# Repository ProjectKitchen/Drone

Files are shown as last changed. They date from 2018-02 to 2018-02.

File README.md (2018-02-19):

# Drone

## Disclaimer
This is drone was created in the winter term 2014 by students in the mechatronics/robotics degree course. It was added to the ProjectKitchen for further development

## Description
The projects aim was to create an inexpensive drone that could be used for swarm experiments. It comprises of the following components:
- A flight controller (MultiWii 328p available at Hobbyking)
- A MOSFET-Driver with DC-motors (can be substituted with brushless motors & ESCs)
- A Bluetooth HC06 module for communication (should be substituted with a WiFi-module)
- A Arduino Micro for communication & as a possible hook for swarm algorithms

## ToDo
- Get a battery for that drone
- Modify the base to be printed on our 3D-printer
- Get stronger motors for acrobatic flights

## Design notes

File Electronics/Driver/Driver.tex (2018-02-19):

\documentclass{article}

\usepackage[utf8]{inputenc}
\usepackage[T1]{fontenc}
\usepackage[ngerman]{babel}
\usepackage{helvet}
\renewcommand{\familydefault}{cmss}
\usepackage[natural, table, fixpdftex, hyperref]{xcolor}
\usepackage{tikz}
\usepackage[european, emptydiodes, arrowmos, smartlabels, siunitx]{circuitikz}
\usetikzlibrary{shapes,arrows,positioning,matrix}

%%%<
\usepackage{verbatim}
\usepackage[active,tightpage]{preview}
\PreviewEnvironment{tikzpicture}
\setlength\PreviewBorder{2pt}%
%%%>

\begin{comment}
:Title: Einzeltreiber-Schaltung
:Copyright: Otrebski
\end{comment}

% Motor taken from: http://tex.stackexchange.com/questions/132076/how-to-draw-a-dc-motor-in-circuitikz
% prepare to create bipoles
\makeatletter
\def\TikzBipolePath#1#2{\pgf@circ@bipole@path{#1}{#2}}
\def\CircDirection{\pgf@circ@direction}
\pgf@circ@Rlen = \pgfkeysvalueof{/tikz/circuitikz/bipoles/length}
\makeatother 
\newlength{\ResUp} \newlength{\ResDown}
\newlength{\ResLeft} \newlength{\ResRight}
% set default motor size
\ctikzset{bipoles/motor/height/.initial=.8}
\ctikzset{bipoles/motor/width/.initial=.8}
% create motor shape
\pgfcircdeclarebipole{}
 {\ctikzvalof{bipoles/motor/height}}
 {motor}
 {\ctikzvalof{bipoles/motor/height}}
 {\ctikzvalof{bipoles/motor/width}}
 {
    \pgfsetlinewidth{\ctikzvalof{bipoles/thickness}\pgfstartlinewidth}
    \pgfextractx{\ResRight}{\northeast}
    \pgfextracty{\ResUp}{\northeast}
    \pgfextractx{\ResLeft}{\southwest}
    \pgfextracty{\ResDown}{\southwest}
  \pgfpathmoveto{\pgfpoint{0.775\ResLeft}{0.2\ResDown}}
\pgfpathlineto{\pgfpoint{\ResLeft}{0.2\ResDown}}
  \pgfpathlineto{\pgfpoint{\ResLeft}{0.2\ResUp}}
  \pgfpathlineto{\pgfpoint{0.775\ResLeft}{0.2\ResUp}}
\pgfpathellipse{\pgfpointorigin}{\pgfpoint{0.8\ResRight}{0cm}}
    {\pgfpoint{0cm}{0.8\ResUp}}
  \pgfpathmoveto{\pgfpoint{0.775\ResRight}{0.2\ResDown}}
    \pgfpathlineto{\pgfpoint{\ResRight}{0.2\ResDown}}
  \pgfpathlineto{\pgfpoint{\ResRight}{0.2\ResUp}}
  \pgfpathlineto{\pgfpoint{0.775\ResRight}{0.2\ResUp}}
  \pgfusepath{draw} %draw motor
    \pgftext[rotate=-\CircDirection]{\textsf{M}}
 }
% create motorto-path style
\def\motorpath#1{\TikzBipolePath{motor}{#1}}
\tikzset{motor/.style = {\circuitikzbasekey, /tikz/to path=\motorpath, l=#1}}
% end of setup

\begin{document}
\pagestyle{empty}

% Define block styles
\tikzstyle{block} = [rectangle, draw, fill=blue!20,
    text width=10em, text centered, minimum height=2em]
\tikzstyle{line} = [draw, latex'-latex', thick]
    
\begin{circuitikz}[auto, node distance =15em]
	\node[anchor=east](start)at(0,0){Flight-Controller};
	\node[nigfete,anchor=G](MOSFET)at(3,0){IPS105N03LG};
	\draw(MOSFET.D) -- ++(0,0.5)node[circ](tmp1){} to[motor] ++(0,2.5)node[circ](tmp2){} -- ++(1,0)node[at end, anchor=west]{Batterie +};
	\draw(start.east) to[R,l=150<\ohm>](MOSFET.G);
	\draw(MOSFET.G) ++(-0.25,0)node[circ](tmp3){};
	\draw(tmp1) -- ++(-1,0) to[diode] ++(0,2.5) --(tmp2);
	\draw(MOSFET.S) -- ++(0,-1.5)node[circ](tmp4){} --++(1,0)node[at end, anchor=west]{Batterie --};
	\draw(tmp3) to[R, l_=10<\kilo\ohm>](tmp3|-tmp4)--(tmp4);
	\node at(-0.5,-2){\scriptsize Driver circiut for DC-motors};
\end{circuitikz}

\end{document}

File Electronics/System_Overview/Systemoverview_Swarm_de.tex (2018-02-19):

\documentclass{article}

\usepackage[utf8]{inputenc}
\usepackage[T1]{fontenc}
\usepackage[ngerman]{babel}
\usepackage{helvet}
\renewcommand{\familydefault}{cmss}
\usepackage[natural, table, fixpdftex, hyperref]{xcolor}
\usepackage{tikz}
\usetikzlibrary{shapes,arrows,positioning,matrix}

%%%<
\usepackage{verbatim}
\usepackage[active,tightpage]{preview}
\PreviewEnvironment{tikzpicture}
\setlength\PreviewBorder{2pt}%
%%%>

\begin{comment}
:Title: Systemarchitektur bei Schwarm
:Copyright: Otrebski
\end{comment}

\begin{document}
\pagestyle{empty}

% Define block styles
\tikzstyle{block} = [rectangle, draw, fill=blue!20,
    text width=11em, text centered, minimum height=2em]
\tikzstyle{line} = [draw, latex'-latex', thick]

\begin{tikzpicture}[auto, node distance =15em, font=\large]
	\node[block](controller){Mikrocontroller};
	\node[block, above right of =controller, node distance = 12em](hive){Schwarmintelligenz};
	\node[block, above of =hive, node distance=6em](com){Kommunikation};
	\node[block, below left of =controller, node distance =10em](gyro){Gyroskop};
	\node[block, below right of =controller, node distance =10em](mag){Magnetometer};
	\node[block, left of =gyro](acc){Beschleunigungsmesser};
	\node[block, right of =mag](baro){Barometer};
	\coordinate[shift={(-2em,2em)}] (FC1) at (acc.west|-controller.north);
	\coordinate[shift={(2em,-2em)}] (FC2) at (baro.south-|baro.east);
	\draw[dashed] (FC1) rectangle (FC2);
	\node[anchor=north west] at (FC1) {Flight-Controller};
	%\node[block, below left of =gyro, node distance = 12em](action){Antrieb};
	\node[block, below of =controller, node distance =15em](action){Antrieb};
	%\node[block, below right of =gyro, node distance = 12em](peripherie){Peripherie};
	\node[block, left of =hive, node distance = 20em](peripherie){Peripherie};
	\path[line] (hive) -- (FC1-|com)node[midway]{Servo-Signal Bus \& Serielle Schnittstelle};
	\path[line] (hive) -- (com)node[midway, right]{Serielle Schnittstelle};
	\path[line] (action) -- (FC2-|action)node[midway, right]{PWM-Signal Bus};
	\path[line] (peripherie) -- (hive)node[midway,above]{I\textsuperscript{2}C-Protokoll};
	\path[line] (controller.west) ++(0,0.5em)-| (acc);
	\path[line] (controller.west) ++(0,-0.5em)-| (gyro);
	\path[line] (controller.east) ++(0,0.5em)-| (baro);
	\path[line] (controller.east) ++(0,-0.5em)-| (mag);
	%\node[block](switch){Switch};
	%\node[block, above of =switch](hmi){HMI};
	%\node[block, below left of = switch](cam){Kamera};
	%\node[block, below right of = switch](robot){Roboter};
	%\node[block, below of = robot](enc-splitter){Encoder-Splitter};
	%\node[block, right of = enc-splitter, node distance = 10 em](encoder){Encoder};
	%\node[block, right of = encoder, node distance = 12.5 em](conveyor){F"orderband};
	%Linien
	%\path[line](hmi)--(switch)node[midway, text width = 4em, text badly centered]{Ethernet- Kabel};
	%\path[line](switch)-|(cam)node[midway, left, text width = 4em, text badly centered]{Ethernet- Kabel};
	%\path[line](switch)-|(robot)node[midway, right, text width = 4em, text badly centered]{Ethernet- Kabel};
	%\path[line](cam)|-(enc-splitter)node[near start, left, text width = 4em, text badly centered]{Daten- Kabel};
	%\path[line](robot)--(enc-splitter) node[midway, right, text width = 4em, text badly centered]{Daten- Kabel};
	%\path[line](enc-splitter)--(encoder) node[midway, above]{Daten-} node[midway, below]{Kabel};
	%\path[line](encoder)--(conveyor) node [midway, above]{mechanische}node [midway, below]{Kupplung};
\end{tikzpicture}

\end{document}

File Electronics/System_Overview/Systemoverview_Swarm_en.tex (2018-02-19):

\documentclass{article}

\usepackage[utf8]{inputenc}
\usepackage[T1]{fontenc}
\usepackage[ngerman]{babel}
\usepackage{helvet}
\renewcommand{\familydefault}{cmss}
\usepackage[natural, table, fixpdftex, hyperref]{xcolor}
\usepackage{tikz}
\usetikzlibrary{shapes,arrows,positioning,matrix}

%%%<
\usepackage{verbatim}
\usepackage[active,tightpage]{preview}
\PreviewEnvironment{tikzpicture}
\setlength\PreviewBorder{2pt}%
%%%>

\begin{comment}
:Title: Systemarchitektur bei Schwarm
:Copyright: Otrebski
\end{comment}

\begin{document}
\pagestyle{empty}

% Define block styles
\tikzstyle{block} = [rectangle, draw, fill=blue!20,
    text width=11em, text centered, minimum height=2em]
\tikzstyle{line} = [draw, latex'-latex', thick]

\begin{tikzpicture}[auto, node distance =15em, font=\Large]
	\node[block, fill=blue!30](controller){Micro-Controller};
	\node[block, above right of =controller, node distance = 12em, fill=green!30](hive){Swarm Intelligence};
	\node[block, above of =hive, node distance=6em, fill=red!30](com){Communication};
	\node[block, below left of =controller, node distance =10em, fill=blue!30](gyro){Gyroscope};
	\node[block, below right of =controller, node distance =10em, fill=blue!30](mag){Magnetometer};
	\node[block, left of =gyro, fill=blue!30](acc){Accelerometer};
	\node[block, right of =mag, fill=blue!30](baro){Barometer};
	\coordinate[shift={(-2em,2em)}] (FC1) at (acc.west|-controller.north);
	\coordinate[shift={(2em,-2em)}] (FC2) at (baro.south-|baro.east);
	\draw[dashed] (FC1) rectangle (FC2);
	\node[anchor=north west] at (FC1) {Flight-Controller};
	\node[block, below of =controller, node distance =15em, fill=yellow!30](action){Propulsion};
	\node[block, left of =hive, node distance = 25em, fill=white!30](peripherie){Periphery};
	\path[line] (hive) -- (FC1-|com)node[midway]{Servo-Signal Bus \& Serial Interface};
	\path[line] (hive) -- (com)node[midway, right]{Serial Interface};
	\path[line] (action) -- (FC2-|action)node[midway, right]{PWM-Signal Bus};
	\path[line] (peripherie) -- (hive)node[midway,above]{I\textsuperscript{2}C-Interface};
	\path[line] (controller.west) ++(0,0.5em)-| (acc);
	\path[line] (controller.west) ++(0,-0.5em)-| (gyro);
	\path[line] (controller.east) ++(0,0.5em)-| (baro);
	\path[line] (controller.east) ++(0,-0.5em)-| (mag);
\end{tikzpicture}

\begin{tikzpicture}[auto, node distance =15em, font=\Large]
	\node[block, fill=blue!30](controller){Micro-Controller};
	\node[block, above right of =controller, node distance = 12em, fill=gray!40](hive){Swarm Intelligence};
	\node[block, above of =hive, node distance=6em, fill=gray!40](com){Communication};
	\node[block, below left of =controller, node distance =10em, fill=blue!30](gyro){Gyroscope};
	\node[block, below right of =controller, node distance =10em, fill=blue!30](mag){Magnetometer};
	\node[block, left of =gyro, fill=blue!30](acc){Accelerometer};
	\node[block, right of =mag, fill=blue!30](baro){Barometer};
	\coordinate[shift={(-2em,2em)}] (FC1) at (acc.west|-controller.north);
	\coordinate[shift={(2em,-2em)}] (FC2) at (baro.south-|baro.east);
	\draw[dashed] (FC1) rectangle (FC2);
	\node[anchor=north west] at (FC1) {Flight-Controller};
	\node[block, below of =controller, node distance =15em, fill=gray!40](action){Propulsion};
	\node[block, left of =hive, node distance = 25em, fill=gray!40](peripherie){Periphery};
	\path[line] (hive) -- (FC1-|com)node[midway]{Servo-Signal Bus \& Serial Interface};
	\path[line] (hive) -- (com)node[midway, right]{Serial Interface};
	\path[line] (action) -- (FC2-|action)node[midway, right]{PWM-Signal Bus};
	\path[line] (peripherie) -- (hive)node[midway,above]{I\textsuperscript{2}C-Interface};
	\path[line] (controller.west) ++(0,0.5em)-| (acc);
	\path[line] (controller.west) ++(0,-0.5em)-| (gyro);
	\path[line] (controller.east) ++(0,0.5em)-| (baro);
	\path[line] (controller.east) ++(0,-0.5em)-| (mag);
\end{tikzpicture}

\begin{tikzpicture}[auto, node distance =15em, font=\Large]
	\node[block, fill=gray!40](controller){Micro-Controller};
	\node[block, above right of =controller, node distance = 12em, fill=green!30](hive){Swarm Intelligence};
	\node[block, above of =hive, node distance=6em, fill=gray!40](com){Communication};
	\node[block, below left of =controller, node distance =10em, fill=gray!40](gyro){Gyroscope};
	\node[block, below right of =controller, node distance =10em, fill=gray!40](mag){Magnetometer};
	\node[block, left of =gyro, fill=gray!40](acc){Accelerometer};
	\node[block, right of =mag, fill=gray!40](baro){Barometer};
	\coordinate[shift={(-2em,2em)}] (FC1) at (acc.west|-controller.north);
	\coordinate[shift={(2em,-2em)}] (FC2) at (baro.south-|baro.east);
	\draw[dashed] (FC1) rectangle (FC2);
	\node[anchor=north west] at (FC1) {Flight-Controller};
	\node[block, below of =controller, node distance =15em, fill=gray!40](action){Propulsion};
	\node[block, left of =hive, node distance = 25em, fill=gray!40](peripherie){Periphery};
	\path[line] (hive) -- (FC1-|com)node[midway]{Servo-Signal Bus \& Serial Interface};
	\path[line] (hive) -- (com)node[midway, right]{Serial Interface};
	\path[line] (action) -- (FC2-|action)node[midway, right]{PWM-Signal Bus};
	\path[line] (peripherie) -- (hive)node[midway,above]{I\textsuperscript{2}C-Interface};
	\path[line] (controller.west) ++(0,0.5em)-| (acc);
	\path[line] (controller.west) ++(0,-0.5em)-| (gyro);
	\path[line] (controller.east) ++(0,0.5em)-| (baro);
	\path[line] (controller.east) ++(0,-0.5em)-| (mag);
\end{tikzpicture}

\begin{tikzpicture}[auto, node distance =15em, font=\Large]
	\node[block, fill=gray!40](controller){Micro-Controller};
	\node[block, above right of =controller, node distance = 12em, fill=gray!40](hive){Swarm Intelligence};
	\node[block, above of =hive, node distance=6em, fill=red!30](com){Communication};
	\node[block, below left of =controller, node distance =10em, fill=gray!40](gyro){Gyroscope};
	\node[block, below right of =controller, node distance =10em, fill=gray!40](mag){Magnetometer};
	\node[block, left of =gyro, fill=gray!40](acc){Accelerometer};
	\node[block, right of =mag, fill=gray!40](baro){Barometer};
	\coordinate[shift={(-2em,2em)}] (FC1) at (acc.west|-controller.north);
	\coordinate[shift={(2em,-2em)}] (FC2) at (baro.south-|baro.east);
	\draw[dashed] (FC1) rectangle (FC2);
	\node[anchor=north west] at (FC1) {Flight-Controller};
	\node[block, below of =controller, node distance =15em, fill=gray!40](action){Propulsion};
	\node[block, left of =hive, node distance = 25em, fill=gray!40](peripherie){Periphery};
	\path[line] (hive) -- (FC1-|com)node[midway]{Servo-Signal Bus \& Serial Interface};
	\path[line] (hive) -- (com)node[midway, right]{Serial Interface};
	\path[line] (action) -- (FC2-|action)node[midway, right]{PWM-Signal Bus};
	\path[line] (peripherie) -- (hive)node[midway,above]{I\textsuperscript{2}C-Interface};
	\path[line] (controller.west) ++(0,0.5em)-| (acc);
	\path[line] (controller.west) ++(0,-0.5em)-| (gyro);
	\path[line] (controller.east) ++(0,0.5em)-| (baro);
	\path[line] (controller.east) ++(0,-0.5em)-| (mag);
\end{tikzpicture}

\begin{tikzpicture}[auto, node distance =15em, font=\Large]
	\node[block, fill=gray!40](controller){Micro-Controller};
	\node[block, above right of =controller, node distance = 12em, fill=gray!40](hive){Swarm Intelligence};
	\node[block, above of =hive, node distance=6em, fill=gray!40](com){Communication};
	\node[block, below left of =controller, node distance =10em, fill=gray!40](gyro){Gyroscope};
	\node[block, below right of =controller, node distance =10em, fill=gray!40](mag){Magnetometer};
	\node[block, left of =gyro, fill=gray!40](acc){Accelerometer};
	\node[block, right of =mag, fill=gray!40](baro){Barometer};
	\coordinate[shift={(-2em,2em)}] (FC1) at (acc.west|-controller.north);
	\coordinate[shift={(2em,-2em)}] (FC2) at (baro.south-|baro.east);
	\draw[dashed] (FC1) rectangle (FC2);
	\node[anchor=north west] at (FC1) {Flight-Controller};
	\node[block, below of =controller, node distance =15em, fill=yellow!30](action){Propulsion};
	\node[block, left of =hive, node distance = 25em, fill=gray!40](peripherie){Periphery};
	\path[line] (hive) -- (FC1-|com)node[midway]{Servo-Signal Bus \& Serial Interface};
	\path[line] (hive) -- (com)node[midway, right]{Serial Interface};
	\path[line] (action) -- (FC2-|action)node[midway, right]{PWM-Signal Bus};
	\path[line] (peripherie) -- (hive)node[midway,above]{I\textsuperscript{2}C-Interface};
	\path[line] (controller.west) ++(0,0.5em)-| (acc);
	\path[line] (controller.west) ++(0,-0.5em)-| (gyro);
	\path[line] (controller.east) ++(0,0.5em)-| (baro);
	\path[line] (controller.east) ++(0,-0.5em)-| (mag);
\end{tikzpicture}

\begin{tikzpicture}[auto, node distance =15em, font=\Large]
	\node[block, fill=gray!40](controller){Micro-Controller};
	\node[block, above right of =controller, node distance = 12em, fill=gray!40](hive){Swarm Intelligence};
	\node[block, above of =hive, node distance=6em, fill=gray!40](com){Communication};
	\node[block, below left of =controller, node distance =10em, fill=gray!40](gyro){Gyroscope};
	\node[block, below right of =controller, node distance =10em, fill=gray!40](mag){Magnetometer};
	\node[block, left of =gyro, fill=gray!40](acc){Accelerometer};
	\node[block, right of =mag, fill=gray!40](baro){Barometer};
	\coordinate[shift={(-2em,2em)}] (FC1) at (acc.west|-controller.north);
	\coordinate[shift={(2em,-2em)}] (FC2) at (baro.south-|baro.east);
	\draw[dashed] (FC1) rectangle (FC2);
	\node[anchor=north west] at (FC1) {Flight-Controller};
	\node[block, below of =controller, node distance =15em, fill=gray!40](action){Propulsion};
	\node[block, left of =hive, node distance = 25em, fill=white!30](peripherie){Periphery};
	\path[line] (hive) -- (FC1-|com)node[midway]{Servo-Signal Bus \& Serial Interface};
	\path[line] (hive) -- (com)node[midway, right]{Serial Interface};
	\path[line] (action) -- (FC2-|action)node[midway, right]{PWM-Signal Bus};
	\path[line] (peripherie) -- (hive)node[midway,above]{I\textsuperscript{2}C-Interface};
	\path[line] (controller.west) ++(0,0.5em)-| (acc);
	\path[line] (controller.west) ++(0,-0.5em)-| (gyro);
	\path[line] (controller.east) ++(0,0.5em)-| (baro);
	\path[line] (controller.east) ++(0,-0.5em)-| (mag);
\end{tikzpicture}

\end{document}

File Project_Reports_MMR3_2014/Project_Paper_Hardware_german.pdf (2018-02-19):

Master-Studiengang Mechatronik/Robotik FH Technikum Wien, Höchstädtplatz 5, A-1200 Wien

FH Technikum Wien Drohne
Mechanische und elektrische Auslegung

Student: Otrebski, Richard, BSc, PK: 1310331006 BegutachterIn: Dipl.-Ing. Dr. Trenker, Markus

Kurzfassung: Kommerziell verfügbare Drohnen werden in zivilen Bereichen, wie der Film- und Spielzeugindustrie, und in militärischen Bereichen zum Kartographieren von Gelände oder Suchen von Personen eingesetzt. Diese Modelle sind jedoch für Studenten und Forscher im Bereich von Schwarmaufgaben nicht interessant, da sie zu viel kosten. Günstige Modelle weisen jedoch nicht den benötigten Funktionsumfang auf um Schwarmexperimente durchzuführen. Die Drohne selbst ist mit ihren verschiedensten Komponenten ein interessantes mechatronisches System. Sie zeigt Studenten was ein funktionierendes System umfasst, und wie man die einzelnen Teile auslegt. Damit eignet sie sich ideal für Studenten um ihr Wissen zu erweitern und ihre Fertigkeiten praktisch anzuwenden. In dieser Arbeit wurde die mechanische und elektrische Auslegung einer preiswerten Drohne für Studenten und Schwarmexperimente dokumentiert. Neben einer groben Abschätzung der Antriebsleistung der Motoren und Propeller, wurde auch eine Treiberschaltung konzipiert, die für bürstenbehaftete Motoren verwendet werden kann. Die verwendete Soft- und Hardware ist oen und erlaubt es so jedem sie an seine Bedürfnisse anzupassen.
Schlüsselwörter: Drohne, Quadcopter, Entwicklung, Bausatz
1. Einleitung

Drohnen sind in der heutigen Zeit immer häu-ger im zivilen und militärischen Bereich anzutreen. Sei es als Spielzeug, als Hilfsmittel um Luftaufnahmen zu erstellen, oder um Personen zu suchen. Da Drohnen ein komplexes mechatronisches System darstellen, eignen sie sich auch als Übungsobjekte für Studenten. Ein weiteres interessantes Feld ist die Schwarmrobotik. Mit ihr können Aufgaben durch die Aufteilung auf mehrere Drohnen schnell und ezient gelöst werden. Da die verfügbaren Drohnen jedoch entweder zu teuer oder zu eingeschränkt sind, wurde an der FH Technikum Wien beschlossen eine eigene Drohne zu entwickeln. In dieser Arbeit wird die mechanische und elektrische Auslegung der Drohne präsentiert.

2. Problem- und Aufgabenstellung

Verfügbare preiswerte Drohnen bestehen meistens aus einem geschlossenen System. Das bedeutet, dass Studenten nicht ohne weiteres auf die Parameter und Sensorwerte der Drohne zugreifen können. Teurere Drohnen, die das erlauben, liegen jedoch meistens weit auÿerhalb des verfügbaren Budgets. Aus diesem Grund soll für die FH Technikum Wien eine eigene Drohne konzipiert und gefertigt werden. Mit ihr soll es Studenten nicht nur möglich sein, kostengünstig mit Drohnen in Berührung zu kommen, sondern es soll ihnen auch ermöglichen Schwarmexperimente durchzuführen. Dazu muss ein oenes und beliebig erweiterbares System geschaen werden.

3. Materialien und Methoden

Um eine kostengünstige Drohne zu bauen, wurde ein Quadcopter konzipiert. Quadcopter sind die häu-gste Art der nicht kommerziellen Drohnen. Dies liegt vor Allem daran, dass wenige Komponenten benötigt werden, und diese sehr schnell zu Ergebnissen führen. Der Name Quadcopter rührt daher, dass vier Motoren verwendet werden.
Die Grundlagen der mechanischen Auslegung benötigt eine ungefähre Abschätzung der Antriebsleistung. Der erzeugte Schub der Motoren setzt sich aus einem statischen und dynamischen Anteil zusammen. Der statische Term sorgt dafür, dass die Drohne in der Luft stehen kann. Der dynamische Term beschränkt die Geschwindigkeit, mit der die Drohne iegen kann.

FSchub = ρ

π
4
d

2 − d

2
N

(pkV u)

2 − vpkV u
(1)

In Gleichung 1 ist eine Abschätzung der Schubkraft ersichtlich. Der Term ρ bezeichnet die Dichte der Luft, d bezeichnet den Durchmesser des Rotors, dN bezeichnet den Durchmesser der Nabe des Propellers, p die Steigung des Rotors. kV bezeichnet den Motorenkennwert und gibt an, wie schnell sich der Motor bei einer gewissen Spannung u dreht. v gibt die Geschwindigkeit der Drohne entgegen der Schubrichtung an. Beachtet werden muss jedoch, dass viele Annahmen getroen wurden. So kann zum Beispiel nicht gesagt werden, dass die Steigung über den gesamten Propeller konstant ist. Die verwendete Steigung des Propellers wurde empirisch ermittelt, in dem an die Motoren eine Spannung angelegt wurde um die Drohne mit einem bekannten Gewicht in der Luft balancieren zu können. Um den gesamten Schub der Drohne zu ermitteln, muss Gleichung 1 für alle Motoren aufgestellt, und danach summiert werden. Der Einfachheit halber kann jedoch bei gleichen Motoren und Propellern mit der Anzahl an Motoren multipliziert werden. Die gewählten Motoren und Propeller erzeugen bei 5 V einen Schub von ≈1,7 N. Gleichung 2 wurde aus dem Kräftegleichgewicht in Hibbeler (2005) abgeleitet. Aus Gleichung 2 kann die Abbildung 1 abgeleitet werden. In ihr ist die benötigte Motorspannung zum schweben in der Luft in Abhängigkeit des Gewichts der Drohne ersichtlich.

FG =4FSchub

mDrohneg =4ρ

π
4
d

2 − d

2
N
(pn)

2

(2)

Angenommen wurde dafür eine Dichte ρ von
1,233 kg m⁻³
. Ersichtlich ist, dass das maximal mögliche Gewicht mehr als doppelt so groÿ wie das Gewicht der Drohne selbst ist. Eine genaue Analyse des entworfenen Designs zeigte, dass die maximal auftretende Spannung im Motorausleger bei 0,36(3) N mm⁻² liegt. Diese liegt weit unterhalb der maximal zulässigen Spannung von 45 ± 3 N mm⁻²
0 | 50 | 100 | 150

0

1

2

3

4

5

Gewicht <g>

Motorspannung <

V

>

Abb. 1: Benötigte Motorspannung zum schweben in der Luft bei gegebenem Gewicht der Drohne.

Die elektrischen Komponenten der Drohne sind wie folgt: der Flight Controller, das Kommunikationsmodul, die Individualintelligenz, die Treiberschaltung und die Motoren. Der Flight Controller ist das Herzstück der Drohne. Er übernimmt die Regelung der Motoren und besitzt eigene Sensoren. Der verwendete Flight Controller ist der MultiWii 328p von Hobbyking. Der Vorteil dieses Flightcontrollers ist, dass er einen 10 DOF-Sensor besitzt (HobbyKing, 2015). Dabei handelt es sich um einen Beschleunigungsmesser, ein Gyroskop, ein Magnetometer und ein Barometer. Der Flight Controller wird direkt mit einem Open-Source-Framework ausgeliefert, dass die Steuerung der Motoren übernimmt. Zusätzlich bietet es eine serielles Schnittstelle zum Auslesen der Sensorrohdaten. Bei dem Kommunikationsmodul handelt es sich um ein Bluetooth-Funkmodul (HC-06), dass über eine serielle Schnittstelle angesprochen werden kann. Die Individualintelligenz besteht aus einem Arduino Micro. Dieser arbeitet in der aktuellen Version nur als Interpreter zwischen der Steuerungs-App, die auf jedem Android Mobiltelefon installiert werden kann, und dem Flight Controller. Der Mikrocontroller bekommt durch das Kommunikationsmodul serielle Anweisungen, die in Servo-Signale zur Steuerung des Flight Controllers umgewandelt werden. Die Treiberschaltung der bürstenbehafteten Motoren war eine komplexe Thematik. Die ersten beiden Versionen wurden als reguläre Transistoren-Treiber mit einem Optokoppler entworfen. Nach Hinweisen in Zach (2010) wurde die Treiberschaltung erneut konzeptioniert. In der letzten Version wurde ein MOSFET verwendet.

Dieser wirkt als spannungsabhängiger Schalter. Mit ihm ist es möglich bis zu 35 A zu schalten bei einem Basisstrom von nur 0,5 mA.

4. Praktische Durchführung

Zur Realisierung der Drohne wurden mehrere Versuche durchgeführt. Im ersten Test wurde ermittelt, welche Spannung der Flight Controller zur Ansteuerung der Motoren verwendet. Im zweiten Test wurde ermittelt, wie der Flight Controller die Motoren ansteuert. Dabei wurde erkannt, dass er ein Servo-Signal mit einer Periodendauer von 2 048 µs verwendet. Durch die Neudenition der Mindest- und Maximalpulsbreite konnte ein PWM-Signal erstellt werden. In dem dritten Test wurde erkannt, dass die entwickelten Treiberschaltungen in Version 1 und 2 nicht für die Ansteuerung der Motoren verwendet werden konnten. Der letzte Versuch befasste sich mit dem Gesamtsystem. Dabei wurde überprüft, ob die Drohne abheben und iegen kann. Die Drohne stellte sich als ugfähig heraus, benötigt aber noch eine genaue Einstellung der Reglerparameter.

5. Ergebnisse

Es wurde eine kleine Drohne von der Gröÿe einer Handäche entworfen und dimensioniert. Der Vorteil an der konstruierten Drohne ist das komplett oene System, und das sie beliebig skalierbar ist. Dank dem oenen System können Studenten die Drohne selbst weiter entwickel und genau an ihre Bedürfnisse oder Experimente anpassen. Die Skalierbarkeit bezieht sich auf den Flight Controller in Verbindung mit der Individualintelligenz und dem Kommunikationsmodul. Diese können für verschiedenste Drohnen mit bis zu acht Motoren verwendet werden. Die entwickelte Treiberschaltung funktioniert bis zu 35 A. Sollte man jedoch in den Bereich dieser Begrenzung kommen, so sollte man schon überlegen bürstenlose Motoren zu verwenden.

6. Zusammenfassung und Ausblick

Es wurde eine ugfähige Drohne konzipiert und gefertigt. Die entstandene Drohne kann von einer App für ein Android-Mobiltelefon aus gesteuert werden. Nachteilig an der aktuellen Parametrierung ist jedoch die hohe Reaktionsrate und der Drift beim Halten der Höhe. Dies kann durch eine korrekte Wahl der Reglerparameter behoben werden. Ebenso sollte die Verbindung zwischen Flight Controller, Individualintelligenz und Kommunikationsmodul neu entworfen werden. Dazu kann eine Leiterplatte entworfen und gefertigt werden.

7. Literaturverzeichnis
Hibbeler, R. C., 2005. Technische Mechanik. 1. Statik. 10. München, Germany: Pearson.

HobbyKing, 2015. MultiWii 328P Flight Controller
w/FTDI | DSM2 Comp. Port. [Online] Ver-
fügbar | unter: | <http://www.hobbyking.com/
hobbyking/store/__27033__MultiWii_328P_ Flight_Controller_w_FTDI_DSM2_Port.html> (http://www.hobbyking.com/hobbyking/store/__27033__MultiWii_328P_Flight_Controller_w_FTDI_DSM2_Port.html) [Zugang am 19.01.2015].

Zach, F., 2010. Leistungselektronik. 4. [online] Berlin, Germany: Springer.

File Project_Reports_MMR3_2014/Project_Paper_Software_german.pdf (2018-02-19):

Master-Studiengang Mechatronik/Robotik FH Technikum Wien, Höchstädtplatz 5, A-1200 Wien

Eine flexiblen Systemarchitektur für smartphonegesteuerte Multicopter-Drohnen

Student: SPULAK, David, BSc, PK: 131033029 BegutachterIn: Dipl.-Ing. Dr. TRENKER, Markus

Kurzfassung: Auf Grund ihrer Stabilität und Manövrierfähigkeit sind Multicopter an der Spitze der Drohnentechnologie. Sie nden einen breiten Einsatzbereich in vielen verschiedenen Industrien, wie der Film- und Spielwarenindustrie aber auch in der Überwachungs- und Militärtechnik. Eine Multicopter-Drohne kann Studenten der FH-Technikum Wien eine herausragende Möglichkeit geben mit einem durch und durch mechatronischen System zu arbeiten und Erönet den Einstieg in das noch sehr junge Forschungsfeld der Schwarmrobotik. Die meisten individuellen elektronischen Teile, die zum Erstellen einer Multicopter-Drohne notwendig sind, sind kommerziell erhältlich. Das Know-How zum Bau einer ferngesteuerten Drohne ist zwar in der Modellbaugemeinschaft vorhanden, für Neulinge und Amateure in diesem Bereich jedoch nur schwer zugänglich. Um diese Wissensdiskrepanz zu schlieÿen wurde im Zuge des Projektes, in dem diese Arbeit entstanden ist, eine Quadcopter-Drohne erstellt, die mit Hilfe einer Smartphone-Applikation gesteuert werden kann. In dieser Arbeit wird die Systemarchitektur der Drohne vorgestellt, die eine Drohnensteuerung über eine Handy-Applikation zulassen. Gezeigt wurde die Einsetzbarkeit dieser Systemarchitektur an einem Prototypen der FHTW-Drohne, der in Laborbedingungen erfolgreich getestet werden konnte.
Schlüsselwörter: Drohne, Quadcopter, Smartphone-Applikation, Steuerung
1. Einleitung

Eine Flugdrohne stellt eine Kombination aus einer Vielzahl an technischen Disziplinen dar. In einem solchen Fluggerät werden Mechanik, Elektrotechnik, Steuerungstechnik und Informatik zu einem durch und durch mechatronischen System vereint. In diesem Sinne ist eine Flugdrohne ein hervorragendes Mittel um Studenten des Studienganges Mechatronik/Robotik das enge Zusammenspiel verschiedener, technisch herausfordernder Gebiete näher zu bringen. In dem Projekt, in dem dieses Paper entstanden ist, ist der erste Schritt in Richtung eines FH Technikum Wien Drohnen Bausatz, der es ermöglicht die Drohnentechnologie einer breiten Masse an Studierenden zugänglich zu machen. Dem groÿen und stetig steigende Anteil an Smartphonebesitzern soll es ermöglicht werden, eine kostengünstige Drohne mit Hilfe ihres Telefons über Bluetooth zu steuern. Mit der Entwicklung einer Drohne kann das Forschungsgebiet der Fachhochschule erweitert werden. Schwarmrobotik ist ein vielseitiges Forschungsfeld, welches, gerade im Gebiet der Flugdrohnen, noch groÿen Neuheitscharakter aufweist. Gerade ein kostengünstiges Fluggerät ist hier ein wichtiger Grundstein für jegliche Forschungs- und Projektarbeit in dieser Richtung. In diesem Paper soll die entworfene Systemarchitektur vorgestellt werden, mit der Multicopter-Drohnen über eine Smartphone-Applikation gesteuert werden können. Diese wurde erfolgreich an einem ersten, ca. Handtellergroÿen Prototypen der FHTW-Drohne getestet.

2. Die Systemarchitektur

Die Systemarchitektur die hier vorgestellt wird ist in Abbildung 1 zu sehen. Es wurde hierbei groÿer Wert auf die Modularität der einzelnen Komponenten gelegt. Dies bedeutet, das einzelne Systemteile einfach und ohne andere Teile u beeinussen einfach ausgetauscht werden können. Damit soll einen einfache Adaption und Erweiterung des Systems für den Einsatz

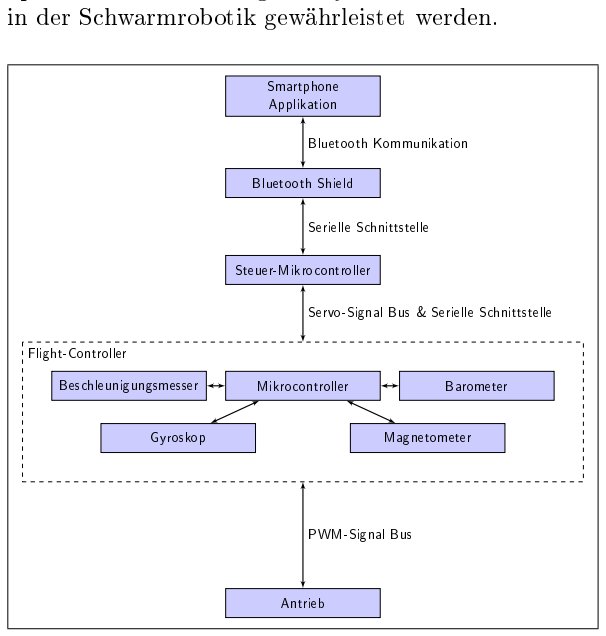
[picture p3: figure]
in der Schwarmrobotik gewährleistet werden.; Mikrocontroller; Steuer-Mikrocontroller; Bluetooth Shield; Smartphone Applikation; Gyroskop; Magnetometer; Beschleunigungsmesser; Barometer; Flight-Controller; Antrieb; Servo-Signal Bus & Serielle Schnittstelle; Serielle Schnittstelle; Bluetooth Kommunikation; PWM-Signal Bus

Abb. 1: Systemarchitektur der FHTW-Drohne

Die Eingabe der Steuerbefehle erfolgt vom Nutzer über eine Smartphone-Applikation, die den Userinput über Bluetooth überträgt. Ein Bluetooth-Shield übersetzt anschlieÿend die Bluetooth Signale in serielle Datenübertragung und übermittelt diese so dem Steuer-Mikrocontroller. Dieser liest schlieÿlich die vom Nutzer eingegebenen Steuerbefehle aus und generiert dazu passende Servosignale. Mit diesen werden dann die Steuereingaben (Antriebsleistung Throttle und Drohnenorientierung Roll, Pitch und Yaw) für den Flight-Controller (FC) gesetzt.
Zentrum der Systemarchitektur ist der FC, der mit Hilfe von diverser Sensorik (Beschleunigungssensor, Gyroskop, Magnetometer und Barometer) für die Stabilisierung der Drohne im Flug sorgt und die gegebenen Steuerbefehle in die entsprechende Drohnenbewegung umsetzt. Dazu steuert er die Motoren über Pulsweitenmodulation (PWM) an und gibt damit die Motordrehzahl vor. Zusätzlich soll eine serielle Kommunikation vom Steuer-Mikrocontroller mit dem Flight-Controller und dessen Sensorik möglich sein. Damit können alle Sensordaten, die der FC verarbeitet auch für etwaige, in der Zukunft erstellte, Drohnenintelligenzen genutzt werden.
2.1. Verwendete Komponenten

Der FC ist das Herzstück der Drohne. Verwendet wurde der MultiWii 328P Flight-Controller (hobbyking.com
R

, 2015), auf dem die MultiWii Software läuft (Dubus, 2015). Bei der MultiWii Software handelt es sich um ein Open-Source Projekt zur Steuerung von funkgesteuerten Fluggeräten. Ursprünglich war die Software auf die in der Nitendo Wii Konsolensteuerung verbauten Gyroskope und Beschleunigungssensoren ausgelegt. Mittlerweile werden jedoch schon eine Vielzahl weiterer Sensoren unterstützt, was zur Entwicklung zahlreicher FC-Boards unterschiedlichster Hersteller geführt hat, die auf diese Software zurückgreifen.
Als Steuerungs-Mikrocontroller wurde das Arduino Micro Board gewählt. Dieses stellt 7 PWM Ausgänge und eine hardwaremäÿige UART Kommunikationsschnittstelle für serielle Universal Asynchronous Receiver Transmitter (UART) Kommunikation zur Verfügung (Arduino, 2015). Diese Schnittstelle wird genutzt um über ein Bluetooth-Shield mit dem Mobiltelefon zu kommunizieren. Für den Datenaustausch mit dem FC kann eine softwareseitige Umsetzung von UART genutzt werden. Damit kann der Steuerungs-Mikrocontroller über das MultiWii Serial Protocoll (MSP) Sensordaten vom FC anfragen.
3. Die Handy-Applikation

Die nale Handyapplikation verfügt über Joysticks, wie sie auch auf Standardfernsteuerungen zu nden sind. Diese sind in der Standard-View-Bibliothek die das Applikationsframework von Android zur Verfügung stellt jedoch nicht vorhanden und mussten erst selbst erstellt werden. Hierbei wurde auf eine möglichst einfache Bedienung Rücksicht genommen, weshalb dem Nutzer nur eine eingeschränkte Steuermöglichkeit angeboten wird. Ein Freiheitsgrad (Yaw) der Steuerung wurde daher entfernt (siehe Abbildung 2). Unter Einsatz von Toggle-Buttons kann die Drohne auf Knopfdruck entsichert oder die Routine zum Halten der Flughöhe aktiviert werden. Des Weiteren wurde ein zusätzliches Settings-Menü erstellt, in dem die Sensitivität der Steuerinput angepasst und Kalibrierungseinstellungen getroen werden können. Falls die Drohne also in neutraler Joystickstellung die Tendenz zeigt sich zu drehen, oder in eine Richtung zu driften können hier Osets im Bereich von −100 bis +100 eingestellt werden um diese auszugleichen.

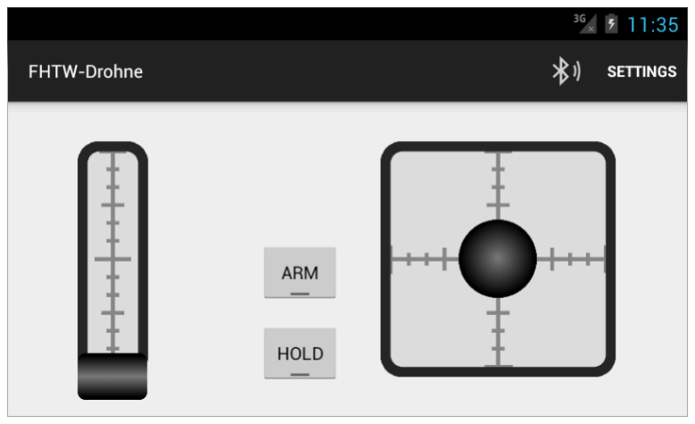
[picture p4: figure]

Abb. 2: Die nale Steuerungs-Handy-Applikation

4. Resultate

Mit Hilfe der im vorangegangen Kapitel beschriebenen Systemarchitektur ist es im Zuge dieses Projekts gelungen eine Mini-Drohne sie passt bequem auf eine Handäche zu erstellen, die mit Hilfe einer Smartphone-Applikation steuerbar ist. Hierbei konnte eine Funkreichweite, innerhalb derer ein sicherer Datentransport sichergestellt ist, von 10 bis 20 m festgestellt werden. Der verbaute FC stabilisiert dabei das Fluggerät und ermöglicht somit das Steuern der Drohne sogar Neulingen im Bereich des Modelluges. Innerhalb dieses Projektes wurde die Funktionsfähigkeit Drohne unter Laborbedingungen (angeschlossen an ein Netzgerät, ohne eigenen Akku) erfolgreich getestet. Das zusätzliche Gewicht, mit dem durch den Akku gerechnet werden kann sollte kein Problem darstellen. Selbst bei erst ca. 50 % der möglichen Antriebsleistung der Motoren konnte die Drohne abheben.

5. Zusammenfassung und Ausblick

In diesem Paper wurde eine Systemarchitektur für Multicopter-Drohnen vorgestellt, die deren Steuerung mit Hilfe einer Handy-Applikation ermöglichen. Bei dem Entwurf des Systems wurde groÿer Wert auf Modularität gelegt. Dies ermöglicht nicht nur den einfachen Austausch einzelner Bauteile durch Komponenten mit ähnlichem Funktionsumfang, sondern auch das Nutzen der hier gezeigten Architektur für Multicopter aller aller Gröÿen und Bauarten. In künftigen Projekten können sehr einfach individuelle Drohnenintelligenzen oder Schwarmverhalten am Steuer-Mikrocontroller vorgesehen werden.

6. Literaturverzeichnis
Arduino, 2015. Arduino Micro. [Online] Verfgbar
unter: | <http://arduino.cc/en/Main/
ArduinoBoardMicro> [Zugang am 17.01.2015].

Dubus, A., 2015. Multiwii. [Online] Verfgbar unter: <http://multiwii.com> [Zugang am 20.01.2015].

hobbyking.com

R
, 2015. Flight Controllers - Hobby-
king. | [Online] | Verfgbar | unter: | <http:
//www.hobbyking.com/hobbyking/store/\_\_ 657\_\_501\_\_Multi_Rotors_Parts-Flight\ _Controller.html> [Zugang am 20.01.2015].

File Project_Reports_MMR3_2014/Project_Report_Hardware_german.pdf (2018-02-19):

## PROJEKTBERICHT

## Im Studiengang Mechatronik/Robotik

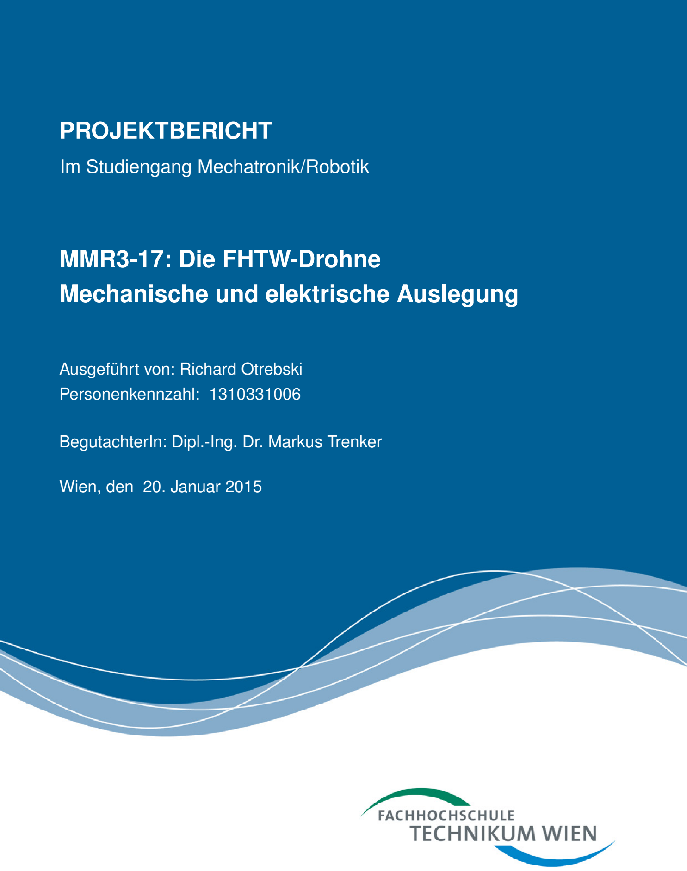
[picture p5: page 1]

## MMR3-17: Die FHTW-Drohne Mechanische und elektrische Auslegung

## Ausgeführt von: Richard Otrebski Personenkennzahl: 1310331006

## BegutachterIn: Dipl.-Ing. Dr. Markus Trenker

## Wien, den 20. Januar 2015

# Kurzfassung

Kommerziell verfügbare Drohnen werden in zivilen Bereichen, wie der Film- und Spielzeugindustrie, und in militärischen Bereichen zum Kartographieren von Gelände oder Suchen von Personen eingesetzt. Diese Modelle sind jedoch für Studenten und Forscher im Bereich von Schwarmaufgaben nicht interessant, da sie zu viel kosten. Günstige Modelle weisen jedoch nicht den benötigten Funktionsumfang auf um Schwarmexperimente durchzuführen.
Die Drohne selbst ist mit ihren verschiedensten Komponenten ein interessantes mechatronisches System. Sie zeigt Studenten was ein funktionierendes System umfasst, und wie man die einzelnen Teile auslegt. Damit eignet sie sich ideal für Studenten um ihr Wissen zu erweitern und ihre Fertigkeiten praktisch anzuwenden.
In dieser Arbeit wurde die mechanische und elektrische Auslegung einer preiswerten Drohne für Studenten und Schwarmexperimente dokumentiert. Neben einer groben Abschätzung der Antriebsleistung der Motoren und Propeller, wurde auch eine Treiberschaltung konzipiert, die für bürstenbehaftete Motoren verwendet werden kann. Die verwendete Soft- und Hardware ist offen und erlaubt es so jedem sie an seine Bedürfnisse anzupassen.

Schlagworte: Drohne, Quadcopter, Entwicklung, Bausatz

# Inhaltsverzeichnis

1. Einleitung | 1
2. Stand der Technik | 1
3. Mechanik | 3
4. Elektronik | 13
4.4.3. I

5. Programmierung | 25
6. Zusammenfassung und Ausblick | 26
Literaturverzeichnis | 28
Abbildungsverzeichnis | 29
Tabellenverzeichnis | 31
Abkürzungsverzeichnis | 32
A. Anhang | 33

# 1. Einleitung

Drohnen sind in der heutigen Zeit ein immer wichtiger werdendes Mittel um Personen zu suchen, oder Gebiete zu kartographieren. Dies kann entweder durch einzelne Drohnen, oder effizienter durch einen ganzen Schwarm erfolgen. Bei einer Drohne handelt es sich um ein unbemanntes Luftfahrzeug, dass entweder durch eine Person gesteuert wird, oder eine Aufgabe in einem Schwarm übernimmt.
Ein Schwarm besteht aus mehreren Drohnen, die untereinander kommunizieren und sich Aufgaben teilen können. Dadurch können zum Beispiel Personensuchen in einem Katastrophengebiet bei einer ausreichenden Anzahl an Drohnen schnell und effizient abgeschlossen werden. Da Drohnen nicht nur im militärischen und zivilen Bereich eingesetzt werden, sollten sich auch Studenten mit der Schwarmthematik beschäftigen.
Drohnen kombinieren eine Vielzahl von technischen Disziplinen; Mechanik, Elektronik und Software gehen Hand in Hand. Damit eignet sich die Drohne als ideales Mittel um Studenten im Feld der Mechatronik das Zusammenspiel der verschiedenen Disziplinen zu zeigen. Da die kommerziell verfügbaren Drohnen aber meistens nicht für Studenten und Schwarmexperimente geeignet sind, muss eine Drohne für die FH Technikum Wien entwickelt werden.
Kommerziell verfügbare Drohnen sind entweder zu teuer, oder besitzen einen Funktionsumfang, der nicht ausreichend ist. Aus diesem Grund soll für die FH Technikum Wien eine Drohne entwickelt werden. Diese Drohne soll möglichst preiswert und komplett für Schwarmexperimente konfigurierbar sein. Die Steuerung der Drohne soll über eine Android-App erfolgen. Dies reduziert nochmals den Preis des Systems, da keine eigene Fernsteuerung gekauft werden muss. Die entwickelte Drohne kann nicht nur an der FH zu Forschungszwecken eingesetzt werden, sondern auch kostenneutral an Studenten verkauft werden. Das bietet zusätzlich einen positiven Werbeeffekt für die FH.
In dieser Arbeit wird die mechanische und elektrische Auslegung einer kleinen und preiswerten Drohne betrachtet. Die Programmierung der Drohne ist in der Arbeit von Herrn Spulak zu finden.

# 2. Stand der Technik

Im folgenden Kapitel wird ein kurzer Überblick über den Stand der Technik präsentiert. Neben einer Auswahl an verfügbaren Multicoptern werden die gängigen Steuerungen vorgestellt.

## 2.1. Multicopter

Multicopter in Form von Drohnen sind heutzutage sehr weit verbreitet. Sie werden nicht nur im militärischen Bereich zur Aufklärung eingesetzt, sondern auch im zivilen Bereich. Dort kommen sie vor Allem im Filmbereich und im Modellbau vor. campilots GmbH (2014) und DIGICOPTER
R Luftaufnahmen & Videoproduktion (2014) stellen neue Wege vor, um kostengünstige Luftaufnahmen zu erstellen. Einen werbetechnisch interessanten Ansatz zeigte Ars Electronica Linz GmbH (2014). Dabei wurden Quadcopter mit LEDs ausgestattet um Figuren an den Nachthimmel zu zeichnen.
In dieser Arbeit werden die kleineren Bauarten der Quadcopter beachtet. Dies kommt daher, da die kleineren Versionen deutlich günstiger sind als die großen. Bei den großen Versionen werden bürstenlose Motoren verwendet. Diese besitzen zwar mehr Leistung, sind aber um einiges teurer und benötigen wieder eine eigene Steuerelektronik.
Ein Beispiel für eine kleine Drohne ist die Hubsan X4. Sie wiegt 36 g, besitzt eine Flugdauer von 9 min und eine Reichweite von ungefähr 100 m (Shenzhen Hubsan Technology Company Limited, 2015). Ein großer Nachteil dieser Drohne ist das geschlossene System. Das bedeutet, dass man keinen Zugang zu den Flugparametern oder auf die Sensordaten besitzt. Deswegen sind diese Drohnen nicht nur nicht für Schwarmexperimente geeignet, sondern auch nicht für Studenten interessant, die selbst die Drohne weiterentwickeln wollen.
Eine andere interessante Drohne ist die Parrot Rolling Spider. Sie wiegt 55 g, besitzt eine Flugdauer von 8 min und eine Reichweite von 20 m (Parrot Public Company, 2015). Diese Drohne besitzt ebenfalls ein geschlossenes System, besitzt jedoch eine größere Funktionalität als die Hubsan X4.

## 2.2. Steuerungen

Zur Steuerung von Drohnen kommt normalerweise ein Flight-Controller (FC) mit einem Funkempfänger zum Einsatz. Beliebte FCs sind das HobbyKing – KK2.0 Multi-rotor LCD Flight Control Board, und auf der Multiwii basierende Systeme. der KK2.0-FC unterstützt bis zu acht Motoren und besitzt ein LCD-Display, um die Reglerparameter auch ohne Computer einstellen zu können. Ebenso ist ein Gyroskop und ein Beschleunigungsmesser auf dem Board zu finden. Die beiden Sensoren liefern somit sechs Freiheitsgrade. Der verwendete Mikrocontroller ist der Atmel ATmega324-PA.
Die MultiWii-Software ist ein Open-Source-Project, dass sich mit der Steuerung verschiedenster funkgesteuerter Fluggeräten beschäftigt. Sie arbeitete ursprünglich mit den Sensoren der Wii-Controllern. Durch ihre große Beliebtheit wurden eine Vielzahl von unterschiedlichen Sensoren in das Projekt aufgenommen und eine Vielzahl von FCs verwendet das MultiWii-Framework. Einer der bekannteren FC ist der Flyduino-NanoWii. Dieser arbeitet mit einem Atmel ATmega 32u4, einem Gyroskop und einem Beschleunigungsmesser. Er unterstützt ebenso bis zu acht Motoren. Zusätzlich können weitere Sensoren über einen Inter-Integrated Cir-

cuit (I

2C)-Port angeschlossen werden. Ein vergleichbarer und kostengünstigerer FC ist der HobbyKing – MultiWii 328P Flight Controller w/FTDI & DSM2 PORT. Dieser FC besitzt neben dem Beschleunigungsmesser und dem Gyroskop auch ein Magnetometer und ein Barometer verbaut.
Ein weiterer bekannter FC ist der Ardupilot. Dieser besitzt einen sehr guten Autopiloten, der autonome Missionen mit GPS-Wegmarken fliegen kann. Dieser FC liegt jedoch deutlich außerhalb des Budgets.

# 3. Mechanik

Die mechanischen Gleichungen wurden Hibbeler (2005), Hibbeler (2006a) und Hibbeler (2006b) entnommen. Neben der Beschreibung der verschiedenen Konfigurationen findet man in diesem Kapitel auch verschiedenen Versionen der Drohne, und die mechanische Nachrechnung der letzten Version. Ebenso wurde eine Abschätzung über die Leistung des Antriebssystems abgegeben.

## 3.1. Konfiguration

Für eine autonome Drohne gibt es verschiedene Konfigurationen. Diese besitzen verschiedene konstruktive Vorschriften. Die verschiedenen Arten der Konfiguration sind wie folgt:

- Bicopter
Diese Anordnung besitzt zwei Rotoren und benötigt für jeden Rotor einen Servo um diesen schwenken zu können.
- Y-Konfiguration
Die Bezeichnung der Y-Konfiguration beruht auf der Anzahl der Motorausleger. Die drei Motorenausleger besitzen im Normalfall einen Winkelversatz von 120◦ zueinander. Diese Konfiguration besitzt drei mögliche Konfigurationen: Y3, Y4 und Y6. Bei der Y3-Konfiguration sind drei Rotoren, wovon einer davon schwenkbar sein muss. Bei der Y4-Konfiguration sind auf einem Motorenausleger zwei Motoren angebracht. Der zweite Motor ist auf der Unterseite angebracht. Die Y6-Konfiguration arbeitet mit sechs Motoren, wobei sich drei Motoren auf der Oberseite und drei auf der Unterseite befinden. Im Allgemeinen wird die Y3-Konfiguration auch Tricopter genannt.
- Quadcopter
Quadcopter sind die häufigste Art der nicht kommerziellen Drohnen. Dies liegt vor Allem daran, dass wenige Komponenten benötigt werden, und diese sehr schnell zu Ergebnissen führen. Der Name Quadcopter rührt daher, dass vier Motoren verwendet werden. Quadcopter gibt es in zwei möglichen Konfigurationen: Quad+ und QuadX. Bei Quad+ liegt die Vorwärtsrichtung fluchtend mit einem Ausleger für die Motoren. Bei QuadX liegt die Vorwärtsrichtung zwischen zwei Auslegern.
- Hexacopter
Hexacopter zeichnen sich durch sechs Motoren aus. Sie bieten eine gewisse Redundanz gegen einen Motorenausfall. Ebenso kann der Hexacopter durch die erhöhte Anzahl an Motoren mehr Gewicht tragen als ein Quadcopter mit den selben Motoren. Wie beim Quadcopter gibt es auch beim Hexacopter zwei Konfigurationen; HexacopterX und Hexacopter+. Beide Konfigurationen sind analog zu den Quadcopter-Konfigurationen.
- Octocopter
Optocopter sind die letzte der gängigsten Arten von Unmanned Aerial Vehicles (UAVs). Bei einem Optocopter werden acht Motoren verwendet. Die Anordnung dieser Motoren erfolgt am häufigsten in drei Kategorien: OptocopterX, Optocopter+ und OptocopterX-CoAx. Die beiden Konfigurationen OptocopterX und Optocopter+ sind analog zu den beiden Konfigurationen des Hexacopters. Bei der CoAx-Konfiguration werden lediglich vier Achsausleger benötigt, da auf jedem Ausleger zwei Motoren befestigt werden. Einer Auf der Ober- und einer auf der Unterseite der Drohne. Diese Konfiguration wird meistens wie der QuadX aufgebaut. Der Optopcopter besitzt die höchsten Anschaffungskosten, da die Motoren mit ihrer Steuerelektronik insgesamt acht Mal verwendet werden. Der große Vorteil ist jedoch, dass die Drohne selbst beim Ausfall mehrerer Motoren noch gelandet werden kann und nicht abstürzt.

Aus Gründen der Einfachheit und aus Kostengründen wird ein regulärer Quadcopter in der Quadcopter X Konfiguration konzipiert. Das Grundlayout ist in Abbildung 1 ersichtlich. Demnach müssen zur Realisierung der Drohne zwei Komponenten gefertigt werden. Eine Basis, und ein Motorhalter. Auf der Basis muss neben dem Flight-Controller (FC) auch noch die Halterung für die Motoren gefertigt werden.

## 3.2. Erster Entwurf

Im ersten Entwurf wurde ein faserverstärktes Kunststoffprofil mit 10 mm Kantenlänge als Verbindungselement zwischen der Basis und den Motorhaltern verwendet.

## 3.2.1. Basis

Die Basis, ersichtlich in Abbildung 2, wurde als Trägerstruktur der Steuerkomponenten entworfen. Deswegen wurde der innere Teil der Drohne komplett entfernt. Damit besitzt die Basis nur

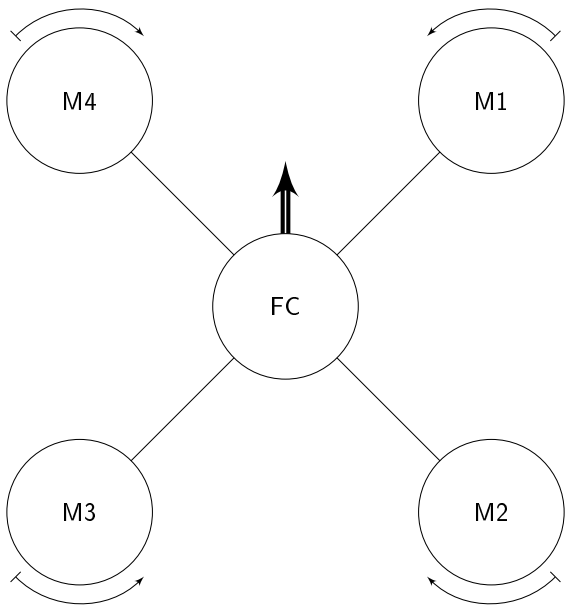
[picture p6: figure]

Abbildung 1.: Drohne in der Konfiguration Quadcopter X

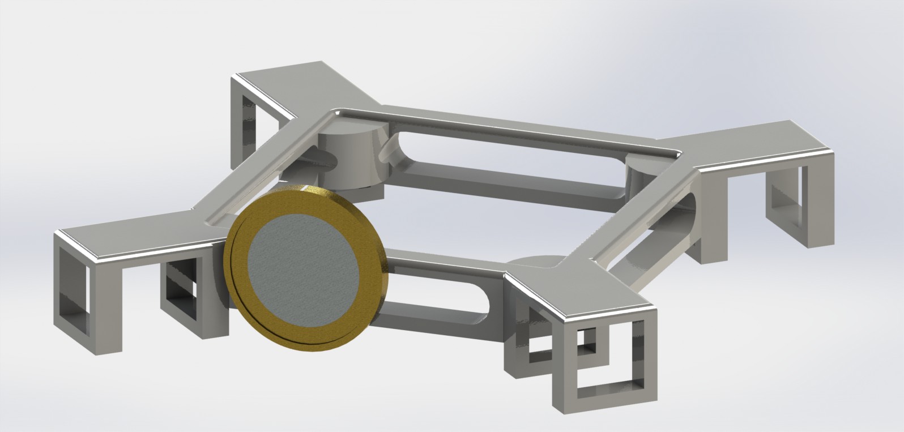
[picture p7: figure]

Abbildung 2.: Basis in der ersten Version mit einem Ein-Euro-Stück als Größenvergleich noch Auflageflächen für den FC und Aufnahmen für die Karbon-Stangen. Innerhalb der Ausnehmung selbst gibt es nur an den Ecken kleine Auflageflächen. Im späteren Verlauf wurde erkannt, dass lediglich drei der vier Auflageflächen verwendet werden können, da der FC an einer Kante Anschlüsse angelötet hat. Die entworfene Basis besitzt ein Gewicht von 11,8 g.

## 3.2.2. Motorhalterung

Die Motorhalter, ersichtlich in Abbildung 3, besitzen neben der Aufnahme für den Motor auch eine Aufnahme für eine Karbon-Stange. Zusätzlich wurde eine Feder an der Unterseite angebracht. Diese sollen im Fall eines Absturzes einen Teil der Energie aufnehmen und die anderen Komponenten vor Schäden bewahren. Nach einer ersten Evaluierung stellte sich jedoch her-

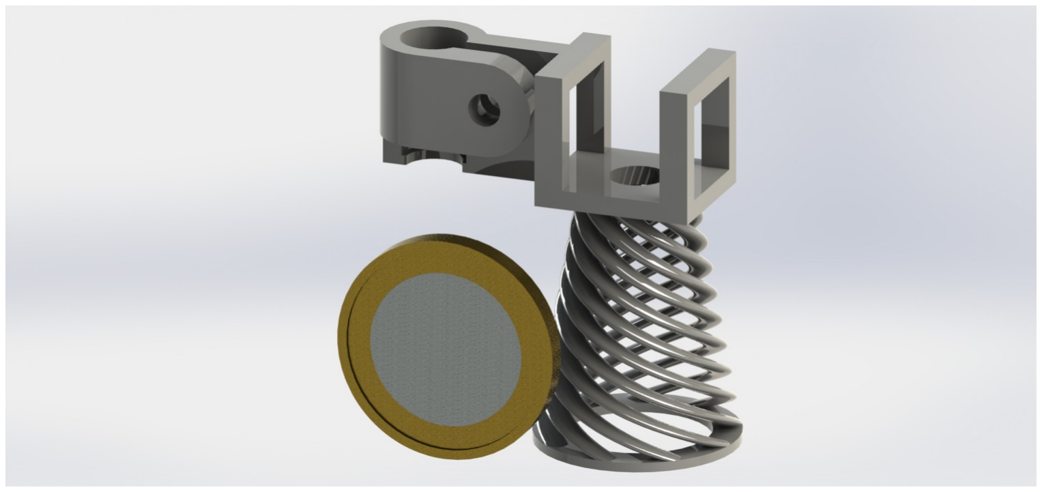
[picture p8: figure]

Abbildung 3.: Motorhalterung in der ersten Version mit einem Ein-Euro-Stück als Größenvergleich

aus, dass der erhoffte Nutzen in keinem Verhältnis zum Gewicht steht. Der entworfene Motorhalter besitzt ein Gewicht von 3,7 g

## 3.3. Zweiter Entwurf

Im zweiten Entwurf, ersichtlich in Abbildung 4, wurde das faserverstärkte Kunststoffprofil verworfen und der Motorhalter direkt in der Basis integriert. Dies bringt mehrere Vorteile. Nicht nur wurde durch das neue Design Gewicht eingespart, sondern die Schubkraft der Propeller wurde besser ausgenutzt. Das neue Gewicht der gesamten Basis beläuft sich auf 7,07 g. Die ausgeschnittenen Träger von der Basis zu den Motoren erlauben das Durchströmen der Luft. Als weiterer Vorteil kann angesehen werden, dass in diesem Bereich der Motortreiber angebracht werden kann und durch den Luftstrom aktiv gekühlt wird. Ebenso wurde in dieser Version an eine Kabeldurchführung von der Basis zu den Motoren gedacht. Damit ist es möglich einen Großteil der Verkabelung in den Korpus der Drohne zu verlegen. Dies bietet den Vorteil, dass die Kabel nur schwer irgendwo hängen bleiben und sich somit schwerer lösen können.

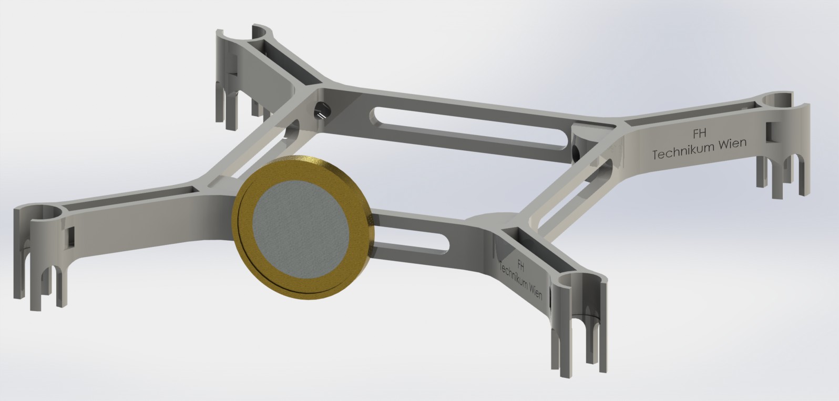
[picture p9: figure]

Abbildung 4.: Basis in der zweiten Version mit einem Ein-Euro-Stück als Größenvergleich

## 3.4. Mechanische Nachrechnung

Für die mechanische Nachrechnung müssen zuerst die Werkstoffdaten des Kunststoffes erhoben werden. Das Material wurde von EOS geliefert und besitzt die in Tabelle 1 aufgelisteten Eigenschaften. Um eine mechanische Nachrechnung durchführen zu können, muss ebenso der

Eigenschaft | Wert
Dichte | 0,9 – 0,95 g cm⁻³
E-Modul (Zug) | 1 700 ± 150 N mm⁻²
E-Modul (Biegung) | 1 240 ± 130 N mm⁻²
Zugfestigkeit | 45 ± 3 N mm⁻²

Tabelle 1.: Materialdaten des Werkstoffes EOSINT P/PA2200 (Quelle: (EOS GmbH, 2014))

Schub des Antriebssystems berechnet werden. Die Nachrechnung des Balkens erfolgt durch das Anwenden der Gleichungen 10–13. Die in diesen Gleichungen benötigten Kräfte werden vom Antriebssystem der Drohne erzeugt. Die allgemeine Formel für den Schub kann aus dem Impulssatz hergeleitet werden.

F =

d
dt (mv)

=

d m
dt v + m

d v
dt

= ˙mv + mv˙

(1)

Mit der Vereinfachung, dass die Geschwindigkeit konstant sein soll, kann der zweite Teil der Gleichung 1, mv˙, vernachlässigt werden. Hierbei muss jedoch berücksichtigt werden, dass es sich bei der Geschwindigkeit v um die Geschwindigkeitsdifferenz zwischen der ausströmenden Geschwindigkeit nach dem Propeller vP und der Geschwindigkeit der Drohne selbst v. Ebenso muss berücksichtigt werden, dass der Massenstrom m˙ mit der Querschnittsfläche des Propellers und der ausströmenden Geschwindigkeit zusammen hängt. Damit ergibt sich die neue

Formel für den Schub. Die Fläche selbst ist von dem Durchmesser des Propellers d und dem Durchmesser der Nabe dN , die für die Montage des Propellers erforderlich ist, abhängig.

FSchub = ˙mv

= ˙m (vP − v)

= ρAvP (vP − v)

= ρ

π
4
d

2 − d

2
N
vP (vP − v)

(2)

Um diese Gleichung zu vereinfachen kann angenommen werden, dass die Geschwindigkeit vP nur von der Steigung p und der Umdrehungszahl n des Propeller abhängig ist. Damit ergibt sich Gleichung 3.

FSchub = ρ

π
4
d

2 − d

2
N

(pn)

2 − vpn
(3)
Diese Formel ist lediglich eine Annäherung an den tatsächlichen Schub, da viele Annahmen getroffen wurden. So kann beispielsweise nicht ohne weiteres gesagt werden, dass die Austrittsgeschwindigkeit der Luft nach dem Rotor nur von der Steigung und der Umdrehungsgeschwindigkeit abhängig ist. Eine Faustregel besagt, dass der statische Schub (v = 0) aller Motoren der Drohne das Doppelte der Gewichtskraft betragen sollte um diese angenehm steuern zu können. Problematisch ist in diesem Fall jedoch, dass in diesem Fall die Propeller ohne jegliche Kennwerte geliefert wurden. Somit muss die Steigung der Propeller empirisch ermittelt werden. Dabei wurden die Drohne komplett zusammen gebaut, und die Motoren mit einem Labornetzgerät versorgt. Danach wurde die Spannung der Motoren soweit erhöht, bis die Drohne sich von selbst in der Luft halten konnte. Mit einem Gewicht von 70 g wurde dies bei einer Spannung von 3,2 V erreicht. Die Propellerdurchmesser d und dN betragen 47 mm und 4 mm. Die Motoren besitzen laut Datenblatt einen kV -Wert von 14 285 V⁻¹ min⁻¹

, dies entspricht 60 000 min⁻¹ bei 4,2 V. Dadurch errechnet sich eine Steigung p von 11,84 mm. Damit beträgt der maximale statische Schub der vier Motoren ≈1,7 N. Mit diesem Werten können zwei unterschiedliche Diagramme angefertigt werden. Zum einen kann die benötigte Motorspannung in Abhängigkeit des Gewichts der Drohne zum Schweben in der Luft berechnet werden. Zum anderen kann die Maximalgeschwindigkeit der Drohne gegen die Erdanziehung berechnet werden. In Gleichung 4 wurde der statische Schub der vier Motoren mit der Gewichtskraft der Drohne gleich gesetzt. Diese Gleichung muss dann lediglich auf die Umdrehungszahl umgeformt werden um das Diagramm 5 zu erhalten.

FG =4FSchub

mDrohneg =4ρ

π
4
d

2 − d

2
N
(pn)

2

(4)

Damit kann der benötigte Schub zum aufheben der Gewichtskraft berechnet, und daraus die Spannung der Motoren abgeleitet werden. Dies kann dadurch ermittelt werden, da die Umdrehungsgeschwindigkeit n direkt proportional zur angelegten Spannung ist und mit kV UM berechnet wird. Der Luftdruck wurde mit 1,233 kg m⁻³ bei 15 ◦C und 1 020 hPa angenommen. In Abbildung 5 ist die benötigte Spannung am Motor zum Schweben der Drohne ersichtlich.

Motorspannung <

V

>

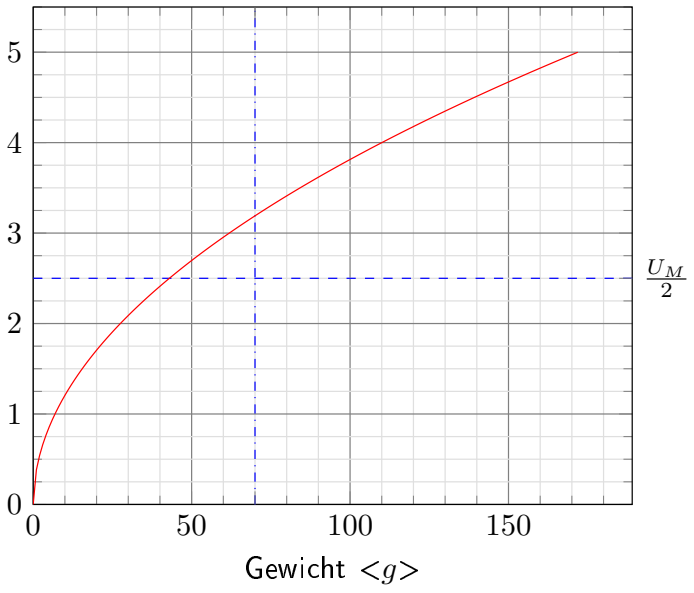
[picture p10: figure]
Gewicht <g>

Abbildung 5.: Benötigte Motorspannung zum schweben in der Luft bei gegebenem Gewicht der Drohne. Die strichpunktierte Linie markiert das Gewicht der FH-Technikum Wien Drohne. Die gestrichelte Linie markiert die halbe Versorgungsspannung. Abgeleitet aus Gleichung 4. Die Dichte der Luft wurde mit 1,233 kg m⁻³ angenommen, die restlichen Parameter sind dem Text zu entnehmen.

Zusätzlich wurde das Gewicht der FH-Technikum Wien Drohne (strichpunktierte Linie) und die halbe Versorgungsspannung der Motoren (gestrichelte Linie) markiert.
Zur Berechnung der Endgeschwindigkeit des Flugzeuges muss die Grunddifferenzialgleichung der Dynamik aufgestellt und gelöst werden.

a =

d v
dt
1

mDrohne

(4FSchub − FG) = d v
dt

(5)

Da die zu erwartenden Geschwindigkeiten relativ klein sein werden, wurde der Luftwiderstand vernachlässigt. Sollte er dennoch berücksichtigt werden, kommt zusätzlich ein negativer, von der Geschwindigkeit abhängiger, Beschleunigungsterm dazu. Nach einsetzen und Umformen der Gleichung ergibt sich Gleichung 6
Z

t

0

dt =mDrohne Zv

0

dv
ρπ
d

2 − d

2
N

(pn)

2 − vpn
− gmDrohne

(6)

t =

mDrohne
ρπnp
d

2 − d

2
N

ln gmDrohne − n
2p

2
d

2 − d

2
N
ρπ
| gmDrohne − np (np − v)
d

2 − d

2
N
ρπ

!
(7)

Nachdem die Integrale in Gleichung 6 gelöst wurden, ergab sich Gleichung 7. Diese wurde auf v = f (t, mDrohne) umgeformt. Dabei wurden mehrere Restriktionen vorgenommen. Die

Geschwindigkeit v selbst muss positiv sein, die Drehzahl n kann durch kV UM ersetzt werden, das Gewicht der Drohne ist durch den statischen Schub beschränkt und kann nicht größer werden als ρ
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
2 − d

2
N

. Damit ist das maximale Gewicht der Drohne bei einer Motorspannung UM von 5 V auf 171,9 g beschränkt. Zusätzlich muss beachtet werden, dass die Geschwindigkeit zum Zeitpunkt 0 ebenfalls 0 m s⁻¹ beträgt. Dadurch ergibt sich Gleichung 8.

v (t, mDrohne) =e

−pkV UMtd²ρπ

mDrohne

∗

pkV UM −

gmDrohne
pkV UMρπ
d

2 − d

2
N

!

∗

e

pkV UMtd²ρπ

mDrohne − e

pkV UMtd²
N ρπ

mDrohne

(8)

Um die Geschwindigkeit in Abhängigkeit von der Zeit und dem Gewicht in einem übersichtlichen Diagramm darzustellen, wurde die Kurvenschar über die verschiedenen Gewichte in einem Diagramm (Abbildung 6) gezeichnet. Um die Endgeschwindigkeit in Abhängigkeit des Gewichts

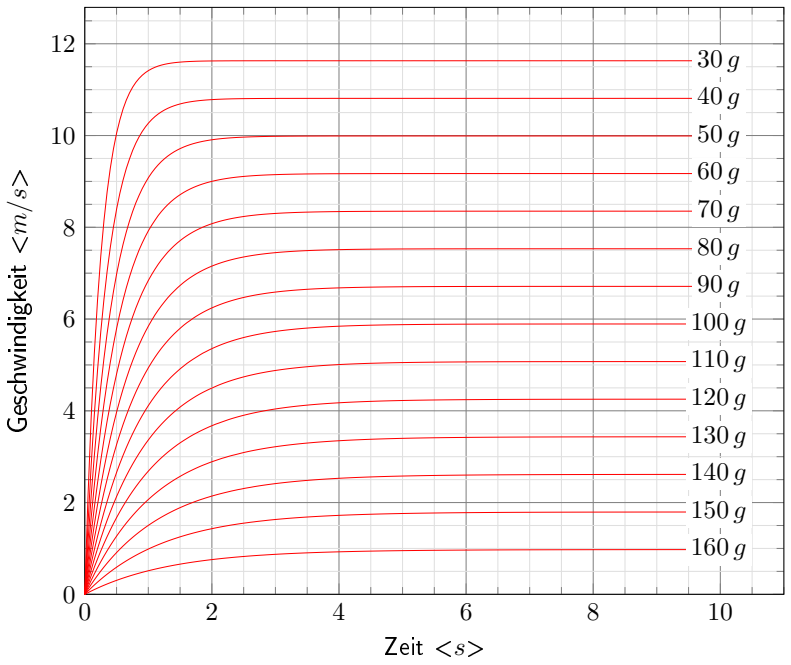
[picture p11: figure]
Zeit <s>; Geschwindigkeit <m/s

Abbildung 6.: Geschwindigkeitsverlauf über die Zeit entgegen der Erdbeschleunigung bei maximaler Motorspannung in Abhängigkeit vom Gewicht der Drohne. Verwendet wurde Gleichung 8; der Luftwiderstand wurde vernachlässigt.

zu ermitteln, muss Gleichung 8 nochmals genauer untersucht werden. Dies geschieht durch die

Bildung des Grenzwertes für den Fall t → ∞. Dies ist in Gleichung 9 ersichtlich.

vE (mDrohne) = limt→∞

v (t, mDrohne)

= pkV UM −

gmDrohne
pkV UMρπ
d

2 − d

2
N

(9)

Die exponentiellen Terme der Gleichung 8 dienen lediglich der Formgebung. Sie konvergieren bei der Grenzwertbildung zu 1. Der Plot der auf diese Weise vereinfachte Term ist in Abbildung 7 ersichtlich. Ersichtlich ist, dass eine Motorenspannung von 2 V bei den ermittelten Parametern

0 | 50 | 100 | 150

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
Gewicht <g>

Endgeschwindigkeit <m/s

>

Abbildung 7.: Endgeschwindigkeit entgegen der Erdbeschleunigung bei verschiedenen Motorspannungen in Abhängigkeit vom Gewicht der Drohne. Verwendet wurde Gleichung 9; der Luftwiderstand wurde vernachlässigt.

unrealistisch ist, da das Gewicht der meisten Drohnen zu groß ist um mit dieser Spannung abheben zu können. Die verwendeten Motoren sind in Kapitel 4.2.2 näher beschrieben. Nachdem die Antriebskräfte ermittelt wurden, muss der Ausleger auf Biegung nachgerechnet werden. Dazu muss das Flächenträgheitsmoment des Trägers ermittelt werden. Die verwendeten Formeln zur Berechnung der Flächenträgheitsmomente bezieht sich Rechtecke. Genauer gesagt, beziehen sich die Formeln auf die Flächenträgheitsmomente um die Hauptträgheitsachsen eines einfachen vollen Rechtecks. Um hohle Rechteckprofile damit berechnen zu können, kann das Flächenträgheitsmoment des äußeren und inneren Rechtecks berechnet werden, und danach dass Innere vom Äußeren subtrahiert werden. Die Achsenaufteilung und

Namenskonvention für die Gleichungen 10 und 11 ist in Abbildung 8 ersichtlich.

JS,x =

bh³
12

(10)

JS,y =

b

3h
12

(11)

Zur Berechnung der Flächenträgheitsmomente wird der Querschnitt des Trägers als eine Summe von verschiedenen Flächen angenommen. Es wird dazu vom Gesamtquerschnitt ein Rechtecke abgezogen. Dies verhindert, dass das Flächenträgheitsmoment verfälscht wird. Da alle

S | x

y

b

h

Abbildung 8.: Skizze zu den Gleichungen 10 und 11.

Rechtecke den selben Schwerpunkt besitzen, müssen die einzelne Trägheitsmomente nicht mehr mit dem Satz von Steiner auf eine gemeinsame Bezugsachse transformiert werden. Die

Fläche | b | h | JSx | JSy | Anmerkung
A1 | 6 mm | 7,5 mm | 210,94 mm⁴ | 135 mm⁴ | +
A2 | 3 mm | 7,5 mm | 105,47 mm⁴ | 16,88 mm⁴ | −

Tabelle 2.: Hilfstabelle zur Berechnung des Flächenträgheitsmoment des Motorauslegers.

Maße der Flächen sind in Tabelle 2 ersichtlich. Mit den ermittelten Werten ergeben sich die Flächenträgheitsmomente JSx und JSy zu 105,47 mm⁴ und 118,12 mm⁴

Die Gleichungen 12 und 13 berechnen die Biegelinie und die Biegespannung entlang des Trägers. Beachtet wird dabei ein Kragträger.

σz,b (y, z) =Mx(z)y
Jx

(12)

wB,Max = −

Ml²
3EJx

(13)

Die maximale Biegespannung tritt in der Randfaser, beim Übergang der Basis in den Träger auf. ebenso kann angenommen werden, dass der Motor eine Kraft erzeugt. Damit können die Gleichungen 12 und 13 umgeformt werden. Zu beachten ist, dass die Länge l 24,21 mm beträgt.

Die maximale Schubkraft eines Motors wurde bereits mit ≈0,4 N ermittelt.

MMax = − FMaxl | (14)

y = −

h
2

(15)

σMax =

FMaxlh
2JSx

(16)

wB,Max =

FMaxl

3
3EJx

(17)

Damit ergibt sich eine maximale Biegespannung von 363 153 Pa beziehungsweise von
0,363 153 N mm⁻²

. Die maximal mögliche Durchbiegung ergibt sich zu 2,9 × 10⁻⁵ mm. Dieser Fall betrachtet die mechanische Verformung eines Motorhalters der zweiten Version. In dieser Betrachtung wird lediglich ein Motor mit voller Spannung versorgt. Andere mögliche Berechnungen umfassen die Verformung im Falle eines unausweichlichem Zusammenstoß mit einer Wand oder einem anderen Objekt. Da diese Situationen jedoch nicht der Regel entsprechen sollen, wird in dieser Arbeit auf die Simulation eines Unfalls verzichtet.

# 4. Elektronik

Die elektronischen Komponenten und deren Auslegung werden in diesem Kapitel erläutert. Es wird neben der Systemarchitektur auch die verschiedenen Arten der Datenübertragung beschrieben die Verwendet werden. Zusätzlich wird die Treiberschaltung zur Ansteuerung der Motoren näher beleuchtet und die verschiedenen Tests ausgeführt.

## 4.1. Systemarchitektur

Die verschiedenen Systemkomponenten einer regulären Drohne können der Abbildung 9 entnommen werden. Da die einzelnen Komponenten des Flight-Controllers (FCs) teurer sind, als das fertige Produkt, wird davon abgesehen, diesen selbst nach zu bauen. In Abbildung 10 ist das Systemschema für die FHTW-Drohne ersichtlich. Dieser soll es möglich sein sich im Schwarm zu formieren, untereinander zu kommunizieren und verschiedene Peripherie anzusprechen. Dies kann dadurch erreicht werden, dass eine Individualintelligenz zwischen das Kommunikationsmodul und den FC gesetzt wird. Diese Individualintelligenz wird von dem Projektteam durch einen Arduino-Mikrocontroller implementiert und soll verschiedenste Aufgaben übernehmen. Die grundlegendste Aufgabe die als erstes implementiert werden muss, ist das automatisierte Landen. Dadurch muss das Steuerungsprogramm für den FC nur soweit abgeändert werden, dass PWM-Ausgänge unterstützt werden. Auf der Individualintelligenz wird

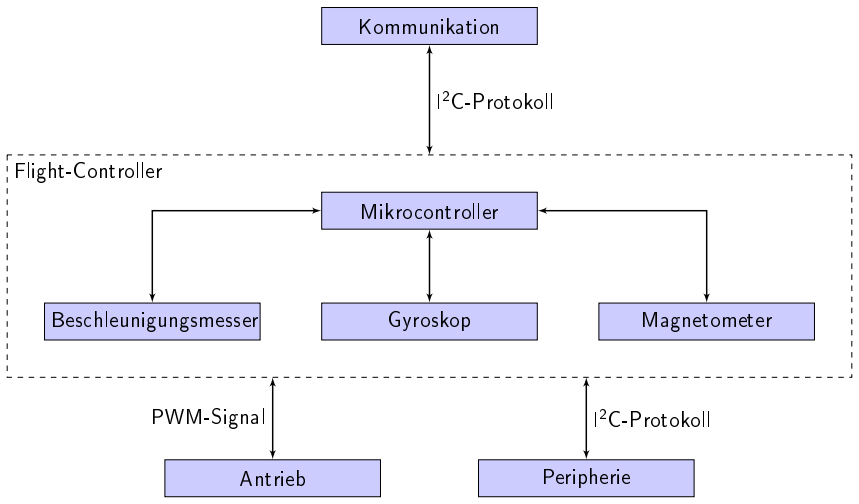
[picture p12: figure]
Mikrocontroller; Kommunikation; Beschleunigungsmesser; Gyroskop; Magnetometer; Flight-Controller; Antrieb; Peripherie; 2C-Protokoll; PWM-Signal

Abbildung 9.: Übersicht über die Systemkomponenten einer regulären Drohne

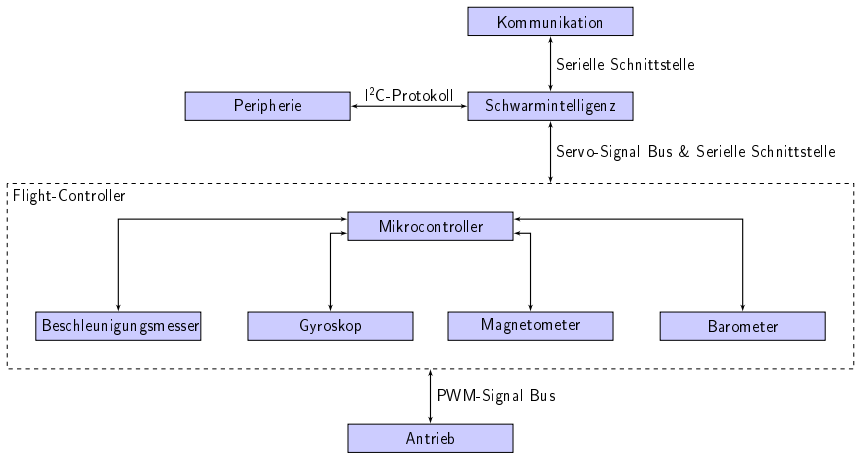
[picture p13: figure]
Mikrocontroller; Schwarmintelligenz; Kommunikation; Beschleunigungsmesser; Gyroskop; Magnetometer; Barometer; Flight-Controller; Antrieb; Peripherie; Servo-Signal Bus & Serielle Schnittstelle; Serielle Schnittstelle; PWM-Signal Bus; 2C-Protokoll

Abbildung 10.: Übersicht über die Systemkomponenten der FHTW-Drohne für Schwamaufgaben dann lediglich der Input des Benutzers und der anderen Drohnen im Schwarm auf Flugbefehle übersetzt.

## 4.2. Komponentenbeschreibung

Im folgenden werden die verschiedenen Komponenten der Drohne kurz beschrieben und ein erster Vergleich angestellt.

## 4.2.1. Flight-Controller

Der FC ist das Herzstück des Unmanned Aerial Vehicle (UAV). Er kombiniert einen Micro-Controller und mehrere Sensoren zu einer funktionalen Einheit.

- Gyroskop: ITG3205 I²C-Adresse:0x68 &ITG3200_LPF_256HZ
- Beschleunigungsmesser: BMA180 I²C-Adresse:0x40
- Kompass: HMC5883L I²C-Adresse:0x1E
- Barometer: BMP085 I²C-Adresse:0x77

Bei dem Layouten des FC sind dem Hersteller jedoch kleinere Fehler unterlaufen. Es wurden zwei Ausgänge des Micro-Controllers nicht mit den korrespondierenden Anschlüssen verbunden. Ebenso ist die Bezeichnung der Anschlüsse nur teilweise korrekt. In Abbildung 11 ist

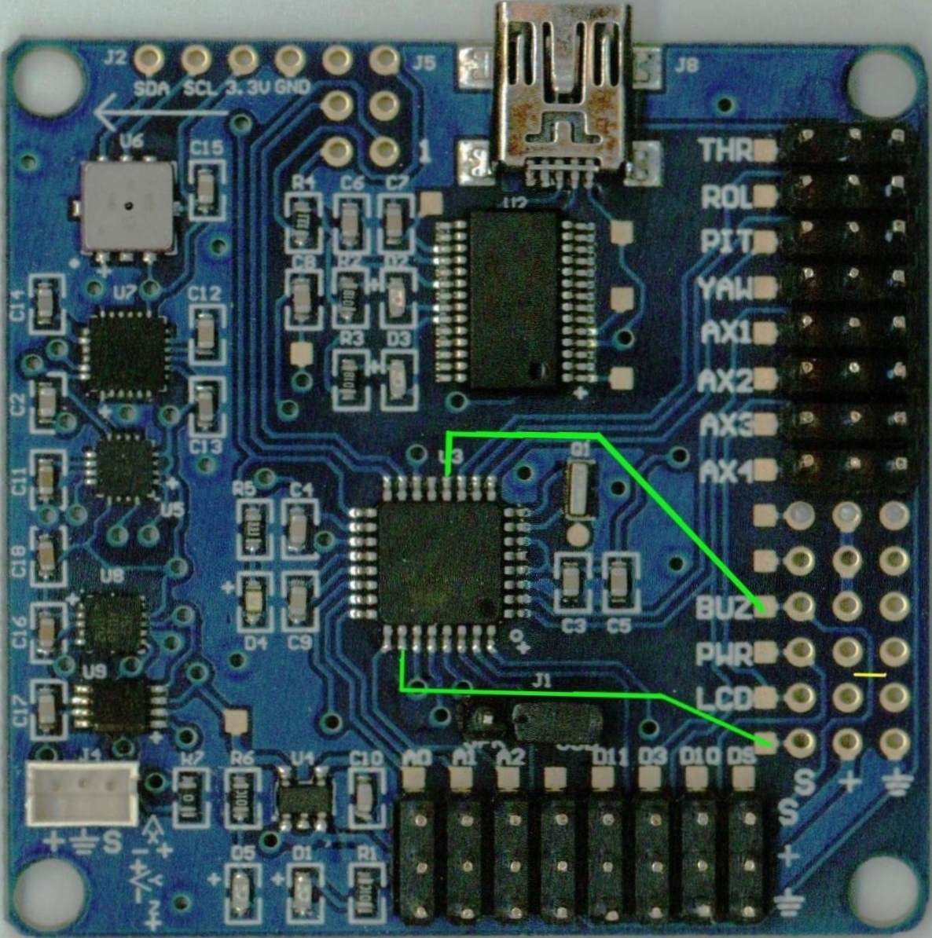
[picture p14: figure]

Abbildung 11.: FC mit den benötigten Verbindungen in Grün und einer vorzunehmenden Trennung in Gelb.

ersichtlich, welche Ausgänge des Micro-Controllers mit den korrespondierenden Anschlüssen verbunden werden müssen. Die Trennung in Gelb ist deswegen notwendig, da sonst der Ausgang D9 auf den Pin des Micro-Controllers verbunden ist.
Die Bezeichnung auf der rechten Seite ist von Oben nach Unten wie folgt: Throttle (D2), Roll (D4), Pitch (D5), Yaw (D6), Auxiliary 1 (D7), RX1 (D0), TX0 (D1), Motoranschluss (D3), A7, A6, Motoranschluss (D9, nach der Reparatur: Warnleuchte bei niedrigem Batteriestand; D8), Auxiliary 2 (D12), TX0 (D1), nicht Verbunden (nach der Reparatur: Spannungsüberwachung der Batterie; A3).
Die Bezeichnung auf der unteren Seite des FC ist von Links nach Rechts: Kamera-Pitch (A0), Kamera-Roll (A1), Kamera-Trigger (A2), Auxiliary 2 (D12), Motoranschluss (D11), Motoranschluss (D3), Motoranschluss (D10), Motoranschluss (D9).
Die Anschlüsse auf der oberen Seite des FC umfassen das I

2C-Interface (A4 & A5 von Links nach Rechts) und das ISP-Interface. Die Spannungsüberwachung der Batterie kann durch einen Spannungsteiler zwischen den Anschlüssen realisiert werden. Dabei wird der negative Pol der Batterie mit einem 33 kΩ-Widerstand, und der positive Pol mit einem 51 kΩ-Widerstand verbunden. Beide widerstände werden dann ebenso verbunden und an dem Anschluss A3 angeschlossen. Die Warnleuchte bei niedrigem Batteriestand kann durch eine LED mit einem Vorwiderstand von 330 Ω realisiert werden.
Um die in Abbildung 1 dargestellte Konfiguration erzeugen zu können, müssen die Motoren wie folgt angeschlossen werden: M1 auf D10, M2 auf D9, M3 auf D11 und M4 auf D3. Alle Informationen zu diesem FC können HobbyKing (2015) entnommen werden.

## 4.2.2. Aktorik

Zur Auswahl für die Aktorik stehen bürstenbehaftete und bürstenlose Motoren. Beide Motorenarten sind Gleichspannungsmotoren. Da die Drohne jedoch nicht nur sehr leicht, sondern auch kostengünstig sein soll, müssen verschiedene Überlegungen angestellt werden. Der Vergleich von bürstenbehafteten zu bürstenlosen Motoren ist in Tabelle 3 ersichtlich. Dadurch ergibt sich,

Bürstenbehaftet | Bürstenlos
Billig | Teuer
Einfache Regelung | Eigener Regler
Niedrige Effizienz | Hohe Effizienz
Wenig Wartung | Keine Wartung
Leichter | Schwerer

Tabelle 3.: Motorenvergleich

dass ein bürstenbehafteter Motor sinnvoll wäre. Dies liegt nicht nur daran, dass diese Motoren günstiger sind, sondern auch daran, dass sie keinen eigenen Speedcontroller benötigen. Da der Flug-Controller keinen Motor direkt betreiben kann, müssen Treiberschaltungen verwendet werden. Die Treiberschaltung für die bürstenbehafteten Motoren besteht aus sehr wenigen Komponenten und ist in Kapitel 4.5 beschrieben.
Da der das angestrebte Zielgewicht der Drohne sehr nah bei dem Gewicht der Hubsan X4 H107 liegen soll, wurden im ersten Schritt die Ersatzteile des Herstellers bestellt. Die Motoren besitzen ein schwarzes und ein weißes Kabel. Unter der Verwendung der Rotoren müssen damit bei dem Rotortyp A muss die schwarze Litze mit Plus versorgt werden; der andere Rotor muss an der weißen Litze mit Plus versorgt werden.

## 4.2.3. Kommunikation

Zur Kommunikation der Drohne mit der Steuereinrichtung stehen zwei Möglichkeiten zur Verfügung, WLAN und Bluetooth. Beide Methoden ermöglichen die kabellose Kommunikation zwischen zwei Modulen. Jedoch bietet Bluetooth viele Vorteile für Drohnen, die mit einer stark limitierten Energieversorgung auskommen müssen. Nicht nur die geringe Reichweite von ungefähr 10 m, sondern auch die geringe Sendeleistung sorgen für einen geringen Stromverbrauch. Damit eignet sich das Bluetoothmodul HC 06 ideal für die Verwendung in einer Drohne. Dadurch wird aber auch die maximale Größe der Ausbreitung des Schwarms begrenzt. Da die Module lediglich eine Reichweite von ungefähr 10 m besitzen, darf dieser Abstand nicht überschritten werden.

## 4.2.4. Individualintelligenz

Um die Individualintelligenz der Drohnen zu erstellen, wird ein Arduino-Mikrocontroller (Arduino Micro) verwendet. Dieser wird zwischen den FC und das Kommunikationsmodul gesetzt. Dadurch können verschiedene Verhalten und Funktionen auf dem Arduino implementiert werden, ohne das Framework des FC überarbeiten zu müssen.

## 4.2.5. Sensorik

In der aktuellen Version der Drohne sind noch keine Sensoren vorgesehen. Sinnvolle Sensoren wären beispielsweise Abstandssensoren, um bei einer autonomen Aufgaben einen Mindestabstand zu möglichen Hindernissen zu gewährleisten.

## 4.2.6. Batterie

Eine mögliche Batterie wäre der Lithium-Polymer (LiPo)-Akku der Firma Parrot. Diese kann mit bis zu 8 A entladen werden. Da die Spannung des Akkus nur 3,7 V beträgt, müssen entweder zwei Akkus verwendet werden, oder für die Versorgung des FC und der Individualintelligenz und des Kommunikationsmoduls wird ein DC-DC-Konverter (LTC3401) verwendet.

## 4.3. Komponentenauswahl

Bei der Komponentenauswahl muss das Hauptaugenmerk auf dem Gewicht der Drohne liegen. In der Tabelle 4 sind die verbauten Komponenten mit dem ungefähren Gewicht angegeben. Der

Komponente | Preis | Gewicht
Flight-Controller | e 23,45 | ≈14,00 g
Kommunikationsmodul | e 3,45 | ≈10,00 g
Individualintelligenz | e 22,60 | ≈13,00 g
Motoren | e 5,65 | ≈10,00 g
Propeller | e 0,89 | ≈8,00 g
Treiberschaltung | e ≈3,00 | ≈3,00 g
Basis | e | ≈7,00 g
| e ≈60,00 | ≈65 g

Tabelle 4.: Auflistung der verwendeten Komponenten mit Gewicht und Preis

Endpreis der Drohne kann weiter reduziert werden, wenn für den FC und die Individualintelligenz günstigere Varianten aus Asien verwendet werden. Diese scheideten für den Prototypen aus, da sie teilweise eine sehr lange Lieferzeit besitzen. Ein passender Ersatz für den FC ist bereits für e16,50 erhältlich. Die Ersparnis bei der Individualintelligenz ist sogar noch größer. Passende Schaltungen können bereits für e4,51 erworben werden.

## 4.4. Datenübertragung

Dieser Abschnitt behandelt die verschiedenen Signale mit denen gearbeitet wird. In den folgenden Abbildungen bedeutet 0 das keine Spannung angelegt ist (logisch Falsch, ausgeschalten), und 1, dass die Spannung angelegt ist (logisch Wahr, eingeschalten).

## 4.4.1. Pulsweitenmodulation

Bei der Pulsweitenmodulation (PWM) wird ein Rechtecksignal mit hoher Frequenz und einem gewissen Duty-Cycle an das Stellglied angelegt. Das Stellglied ist in diesem Fall die in Abschnitt 4.5 dargestellte Treiberschaltung. Bei der PWM kommt es dementsprechend auf das Verhältnis, der Duty-Cycle genannt wird, von Ton zu T an. Über PWM können nicht nur Motoren geregelt, sondern auch LEDs gedimmt werden. In Abbildung 12 ist ein PWM-Signal mit einem Duty-Cycle von 12,5 % ersichtlich. Die verwendete PWM-Frequenz des FCs beträgt 490 Hz.

T

Ton

0

1

Abbildung 12.: PWM-Signal mit einem Duty-Cycle von 12,5 %.

## 4.4.2. Servo-Signal

Wie die Pulsweitenmodulation ist auch das Servo-Signal ein Rechteck-Signal. Bei dem Servo-Signal kommt es jedoch nicht auf den Duty-Cycle, sondern auf die Pulsbreite an. Die Periodendauer T liegt im Normalfall zwischen 5 ms und 25 ms. Eine Pulsbreite von 1 ms korrespondiert

T

Neutral
1500µs

0

1

Abbildung 13.: Servo-Signal korrespondierend zur Neutral-Position.

in Normalfall mit der Minimalposition, 1,5 ms mit der Neutralposition und 2 ms mit der Maximalposition. Bei Throttle korrespondiert die Pulsweite von 1 ms mit keine Schub, und 2 ms mit dem maximal möglichen Schub.

4.4.3. I

2C

Bei Inter-Integrated Circuit (I

2C) handelt es sich um einen seriellen Datenbus. Dieser besteht aus einem Master, der alle anderen Komponenten abfragt, und aus einem oder mehreren Slaves. Die Datenübertragung wird immer vom Master initiiert. Die Datenübertragung wird eingeleitet, in dem der Datenkanal auf logisch 0 gezogen wird, während das Clock-Signal logisch 1 liefert. Danach wird, jedes mal wenn das Clock-Signal eine logische 0 liefert, die Datenleitung gesetzt (siehe Set in Abbildung 14). Die Daten werden übernommen, wenn Clock eine logische 1 liefert (siehe Sample in Abbildung 14). Gestoppt wird die Datenübertragung durch das ziehen der Datenleitung auf logisch 1, während das Clock-Signal ebenfalls logisch 1 sendet.

Start | Set | Sample | Set | Sample | Stop

## Data Clock

Abbildung 14.: I

2C-Signal bei einer Übertragung von 2 Bit.

## 4.4.4. MultiWii Serial Protocol

Das MultiWii-Framework bietet ein serielles Protokoll zum Auslesen und Setzen verschiedenster Werte. Für die FHTW-Drohne bietet sich diese Schnittstelle an, da durch sie sehr einfach die Werte des Beschleunigungsmessers, des Gyroskops des Magnetometers und die geschätzte Flughöhe ermittelt werden können. Die Dokumentation¹ des Protokolls legt offen, dass es 37 Befehle gibt. Davon sind jedoch nur zwei Befehle interessant: MSP_RAW_IMU und MSP_ALTITUDE. Der erste Befehl gibt die benötigten Daten des Beschleunigungsmessers, des Gyroskops und des Magnetometers aus. Der zweite Befehl gibt die geschätzte Flughöhe in Zentimetern aus.

## 4.5. Treiberschaltung

Die folgende Treiberschaltung dient dem Betreiben der Gleichstrommotoren für die Drohne. Das Buch Zach (2010) wurden als Literatur verwendet. Die Schaltung des Treibers ist in Abbil-

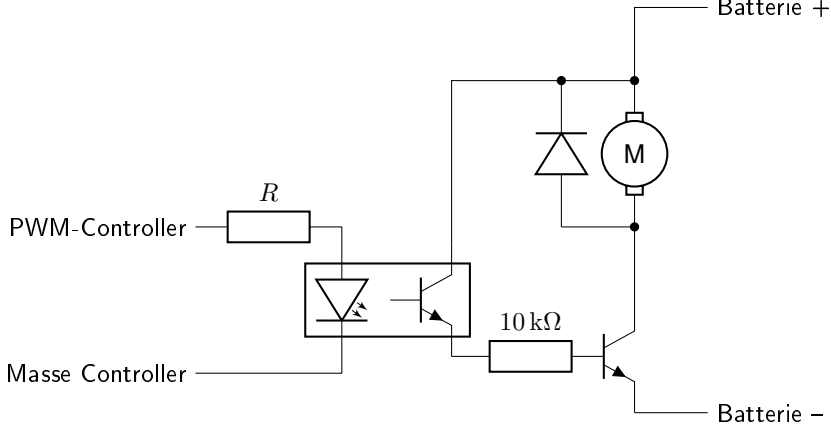
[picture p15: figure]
PWM-Controller; Masse Controller; Batterie 

Batterie + Abbildung 15.: Schaltplan des Motorentreibers in Version 1

dung 15 ersichtlich. Der Wert R des Vorwiderstands für die LED des Optokopplers richtet sich

1http://www.multiwii.com/wiki/index.php?title=Multiwii_Serial_Protocol dabei nach dem verwendeten Optokoppler, und der verfügbaren Spannung des Mikrocontrollers. Als praktikabler Wert bei 5 V Speisespannung des PWM-Controllers ergaben sich 390 Ω. In Versuchen stellte sich heraus, dass diese Treiberschaltung mit dem Motor selbst nicht sehr gut funktioniert. Dies ist in den Aufnahmen mit dem Oszilloskop in Abbildung 16 ersichtlich. Diese Problematik kann durch einen Pull-Down-Widerstand gelöst werden. Der Pull-Down-

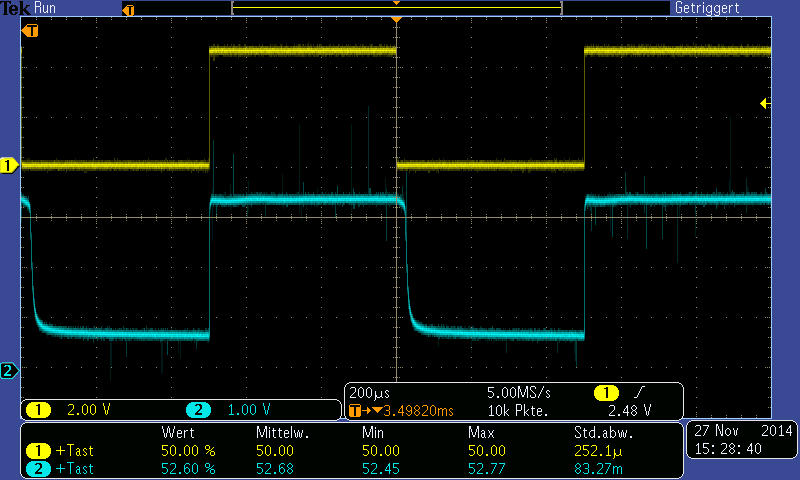
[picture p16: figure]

Abbildung 16.: Übertragungsfunktion der Treiberstufe in Blau auf ein PWM-Signal in Gelb ohne Pull-Down-Widerstand

Widerstand repräsentiert eine Verbindung des Basis-Anschlusses des Leistungstransistors mit dem Emitter-Anschluss. Neben dem Pull-Down-Widerstand wurden auch die Werte der Widerstände neu gewählt. Durch den Pull-Down-Widerstand konnte einer saubere Schaltschwelle

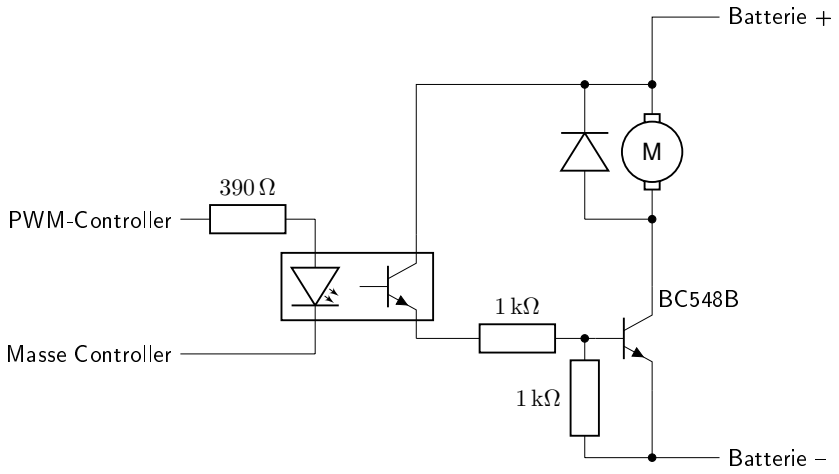
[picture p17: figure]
PWM-Controller; Masse Controller; Batterie ; Batterie +

Abbildung 17.: Schaltplan des Motorentreibers in Version 2

realisiert werden. dies ist durch die Messung in Abbildung 18 ersichtlich. Zu erkennen ist, dass mit dem Pull-Down-Widerstand das Blaue Signal im ausgeschalteten Zustand auf 0 V (gekennzeichnet durch die Marke auf der linken Seite) abfällt. In Abbildung 16 sieht man, dass das Signal nicht auf 0 V abfällt. Ohne Pull-Down-Widerstand kann bei höheren Schaltfrequenzen

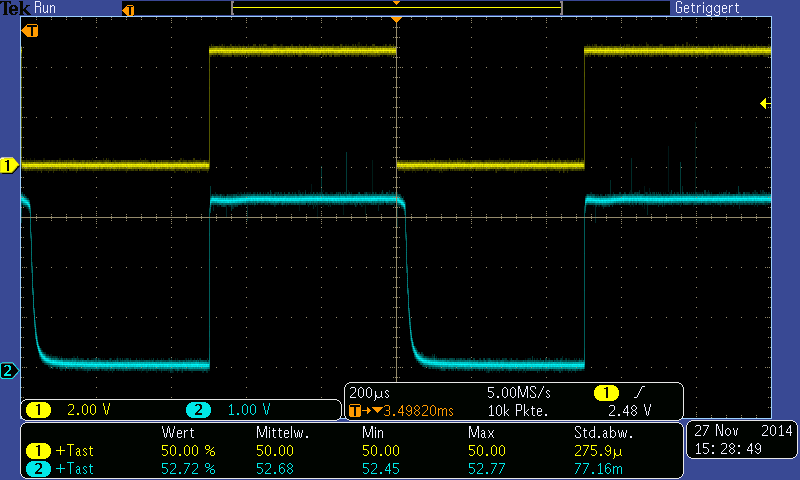
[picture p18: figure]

Abbildung 18.: Übertragungsfunktion der Treiberstufe in Blau auf ein PWM-Signal in Gelb mit Pull-Down-Widerstand

der Transistor nicht schnell genug abschalten. Damit erreichte der Motor schon bei einem Duty-Cycle von 3 % die maximale Drehzahl. Bei einem Versuch mit den Propellern auf den Motoren ergab sich, dass der Strom auf 1,5 A anstieg. Aus diesem Grund muss die Treiberschaltung in eine Version 3 überführt werden. Auf Grund des höheren Stroms muss statt einem regulären Transistor ein Metall-Oxid-Halbleiter-Feldeffekttransistor (MOSFET) verwendet werden. Diese sind für höhere Ströme und Leistungen gedacht. Durch den N-Kanal-MOSFET wird der Strom des Motors nicht mehr beschränkt. Dies war bei den regulären Transistoren der Fall, da diese nur ein gewisses Vielfaches des Basisstromes schalten können.

## 4.6. Tests

Im folgenden werden alle elektronischen Tests dokumentiert. Insgesamt wurden vier Tests durchgeführt. Im vierten Test wurde überprüft, ob die entwickelte Drohne flugfähig ist.

## 4.6.1. Erster Test

Im ersten Test wurden auf die Eingänge des FC verschiedene Servo-Signale angelegt. Dabei stellte sich heraus, dass der FC mit 3,3 V und 5 V arbeiten kann. Ebenso wurde die Sequenz zum Armen definiert.

1. 0 % Throttle =⇒ 1 ms Pulsbreite

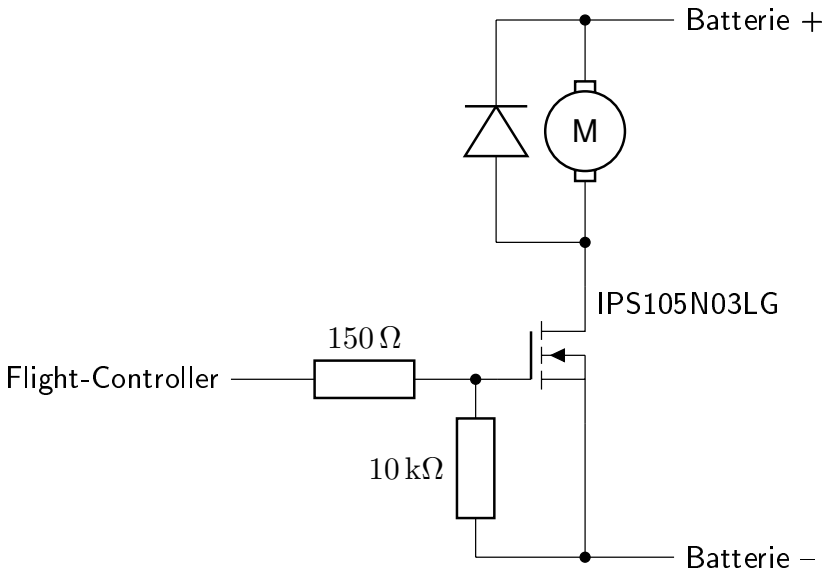
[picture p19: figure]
Flight-Controller; IPS105N03LG; Batterie +; Batterie 

Abbildung 19.: Schaltplan des Motorentreibers in Version 3

2. 100 % Yaw =⇒ 2 ms Pulsbreite
3. Warten bis das Blaue Licht beginnt zu blinken.
4. 0 % Yaw =⇒ 1,5 ms Pulsbreite

Der FC Disarmed automatisch wenn Throttle längere Zeit auf 0 % geschalten ist.

## 4.6.2. Zweiter Test

In diesem Test wurde das Verhalten der Treiberschaltung getestet. Als Erstes musste ermittelt werden, wie der FC die Motoren steuert. Die Tests ergaben, dass ein Servo-Signal verwendet wird um die Motoren zu steuern. Dieses Servo-Signal besitzt eine Periodendauer von 2,04 ms und eine Spannung von 5 V.
Da die Motoren jedoch direkt angesteuert werden, muss der Output als PWM-Signal vorliegen. Dazu müssen Teile des Frameworks geändert werden. Dies wird in Kapitel 5.1 näher erläutert. Zu beachten ist, dass mehrere Variablen angepasst werden müssen. Die Pulsbreite in Abbildung 20 korrespondiert mit dem in der Konfigurationsdatei eingestelltem Wert von 1 150 µs. Die Pulsbreite in Abbildung 21 korrespondiert mit der Neutralstellung von 1 500 µs. Die Pulsbreite in Abbildung 22 korrespondiert mit dem in der Konfigurationsdatei eingestelltem Wert
von 1 850 µs.

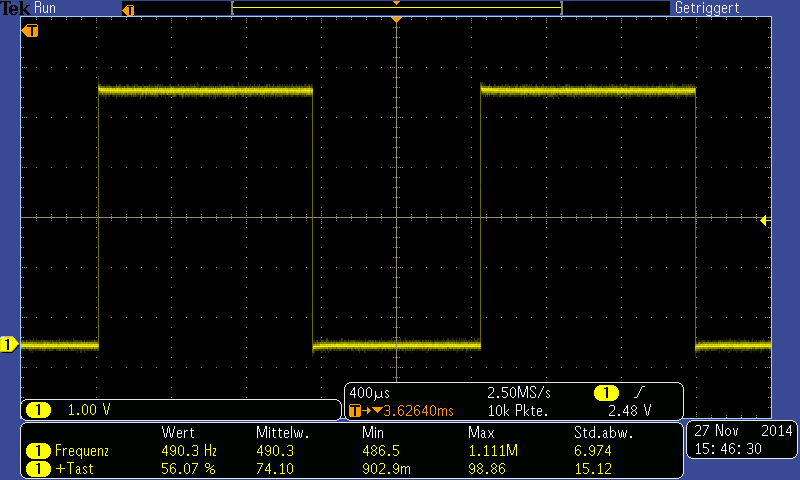
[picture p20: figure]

Abbildung 20.: Servo-Signal des FC in Minimal-Stellung.

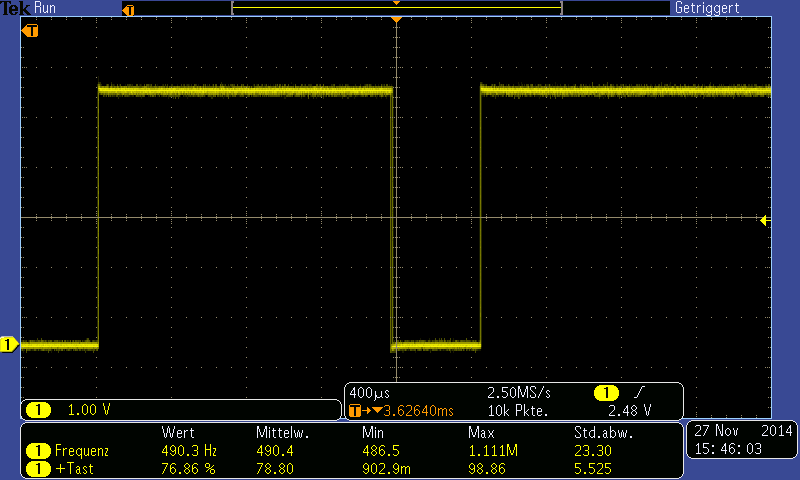
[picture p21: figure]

Abbildung 21.: Servo-Signal des FC in Neutral-Stellung.

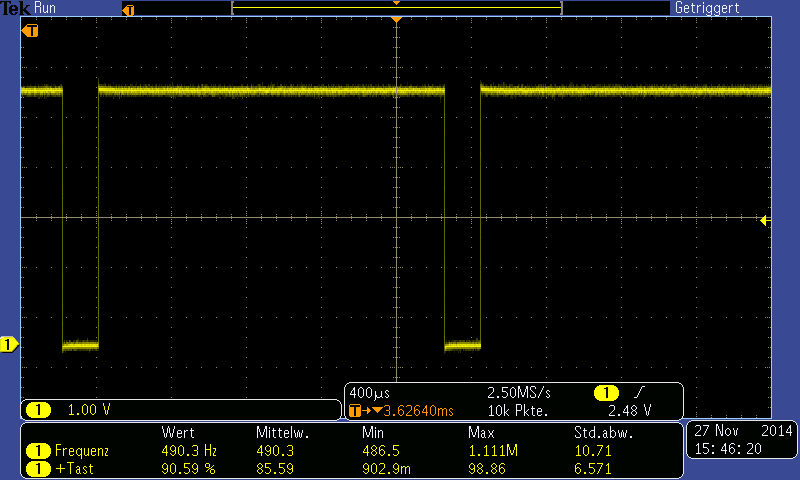
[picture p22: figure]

Abbildung 22.: Servo-Signal des FC in Maximal-Stellung.

## 4.6.3. Dritter Test

Beim dritten Test wurde der Strombedarf der Motoren gekoppelt mit den Motoren empirisch ermittelt. Dabei wurde ersichtlich, dass die Motoren nicht mit der Treiberschaltung in Version Zwei verwendbar waren. Dies liegt an dem hohen Stromverbrauch der Motoren.

## 4.6.4. Vierter Test

Im vierten Test wurde überprüft, ob die Drohne fliegen kann. In den ersten Versuchen konnte sich die Drohne nur leicht bewegen. Dies lag daran, dass das verwendete Netzgerät maximal 3 A liefern konnte. Nach Wahl der eines anderen Netzgerätes war der Flug der Drohne kein Problem. Neben 5 V Versorgungsspannung wurden auch 7,4 V getestet. Die Motoren halten diese Spannung problemlos aus, solange nicht länger als fünf Minuten durchgehend geflogen wird. Danach benötigen die Motoren eine kurze Pause zum abkühlen. Da das System auch mit 7,4 V versorgt werden kann, wird ein DC-DC-Buck-Konverter benötigt, um den FC, die Individualintelligenz und das Kommunikationsmodul mit 5 V zu versorgen. Durch die Versorgungsspannung mit 7,4 V können LiPo-Akkus verwendet werden.

# 5. Programmierung

Die Programmierung der Drohne basiert auf drei Säulen. Dem Framework des FC, dem Framework des Arduino, und die App selbst. Genauere Angaben zur Programmierung sind in der Arbeit meines Kollegen Herrn Spulak zu finden.

## 5.1. Framework – Flight-Controller

Das Framework des FC besteht aus eine Anzahl an fertigen Programmteilen, und einer Konfigurationsdatei. Der Benutzer muss nur die Konfigurationsdatei an seine Bedürfnisse anpassen. Die Drohne gliedert sich in sieben Abschnitte; Das grundlegende Setup, die typen-spezifische Konfiguration, das RC-Setup, alternative CPUs und Leiterplatten, alternatives Setup, optionale Funktionalität und Optionen zum Tunen und für Entwickler. Im grundlegenden Setup wird die Motorenkonfiguration ausgewählt und die Pulsbreite für die Motoren, beziehungsweise für die Geschwindigkeitsregler für bürstenlose Motoren definiert. Die Multiwii arbeitet mit einer Periodendauer von 2 048 µs. Standardmäßig sendet die Multiwii an die Motoren ein Signal mit einer Pulsbreite von 1 000 µs. Sobald die Drohne bereit zum Fliegen ist, arbeitet sie in einem Bereich von 1 150 µs – 1 850 µs. Um die bürstenbehafteten Motoren zu steuern, wurden dieser Werte entsprechend angepasst und auf 200 µs und 400 µs – 2 000 µs festgelegt. Dies entspricht einem Duty-Cycle von ≈10 % wenn die Drohne nicht bereit zum Abflug ist, und einem verfügbaren Bereich von ≈20 % – ≈97 %. Damit ist sofort erkennbar, wenn die Drohne flugbereit ist. Als nächs-

tes wurde #define I2C_SPEED 400000L, #define INTERNAL_I2C_PULLUPS, #define

RCAUXPIN12, #define FREEIMUv035_BMP und #define MAG_ORIENTATION(X, Y, Z)

{magADC[ROLL] = -Y; magADC[PITCH] = X; magADC[YAW] = Z;} gesetzt. Alle an-
deren Werte blieben unverändert. Die einzige Datei, die editiert werden musste, ist die

config.h.

## 5.2. Framework – Arduino

Die Arduino-Plattform bietet eine komplette Ansteuerung eines Atmel-Mikrocontrollers mit mehreren Bibliotheken. Diese Bibliotheken bieten einen einfachen Einstieg in die Welt der Mikrocontroller. Das implementierte Framework agiert als Interpreter zwischen der Telefon-App und dem FC-Framework. Der Arduino ist über die serielle Schnittstelle mit dem Bluetooth-Modul und über die regulären PWM-fähigen Output-Pins mit dem FC verbunden. Aktuell sind Befehle für das Setzen von Throttle, Roll, Pitch, Yaw, das Armen und Disarmen, und für das Halten der aktuellen Höhe. Das Befehlslayout sieht folgendermaßen aus: *[Code]|[Wert]#. Dabei steht
* für den Beginn einer Befehlssequenz und # für das Ende. | ist das Trennzeichen zwischen
dem Befehl und eines benötigten Werts.

## 5.3. App

Die App wurde für das Android-Betriebssystem entwickelt. Mit ihr ist es möglich den Throttle-, Roll- und Pitch-Wert zu setzen. Ebenso kann die Drohne die aktuelle Höhe halten, und scharf geschalten werden. Zusätzlich können über ein Einstellungsmenü die Sensitivität der Inputs und eine Winkelkorrektur eingestellt werden.

# 6. Zusammenfassung und Ausblick

In dieser Arbeit wurde die mechanische und elektrische Auslegung einer kostengünstigen Drohne dokumentiert. Diese Drohne bietet auf Grund ihrer Konzeptionierung einen uneingeschränkten Funktionsumfang. Dies bietet Studenten die Möglichkeit, die Parameter der Drohne selbst zu verändern. Ein weiterer Punkt ist, dass die Drohne in der aktuellen Konfiguration beliebig skaliert werden kann. Ab einem gewissen Punkt muss lediglich beachtet werden, dass keine bürstenbehafteten Motoren mehr verwendet werden können. Danach müssen bei der Verwendung von bürstenlosen Motoren die Standardpulsbreiten wieder eingestellt und elektronische Geschwindigkeitsregler verwendet werden.
In diesem Projekt wurde der Grundstein für eine Drohne der FH Technikum Wien gelegt. Es gibt noch kleinere Defizite, die in einer weiteren Arbeit ausgebessert werden können. Die derzeitige Verbindung der Individualintelligenz, des Bluetooth-Moduls und des Flight-Controllers kann sehr viel eleganter durch eine selbst geätzte Platine gelöst werden. Dadurch kann ebenso der Schwerpunkt der Drohne genauer kontrolliert werden. Ein anderer Punkt ist, dass die aktuellen elektrischen Verbindungen nicht zur schnellen De- und Montage gedacht sind. Dies kann durch Steckverbindungen gelöst werden.

# Literaturverzeichnis

Ars Electronica Linz GmbH, 2014. Spaxels. [] Verfügbar unter: <http://www.aec.at/spaxels/> [Zugang am 20.10.2014].

campilots GmbH, 2014. campilots - Mini Helicopter Filmaufnahmen. [] Verfügbar unter: <http: //www.campilots.com/de/home.html> [Zugang am 20.10.2014].

DIGICOPTER

R Luftaufnahmen & Videoproduktion, 2014. DIGICOPTER.DE. [] Verfügbar unter: <http://digicopter.de/de/luftaufnahmen/> [Zugang am 20.10.2014].

EOS GmbH, 2014. Produktinformation EOSINT P/ PA2200 - Pulver. [Datenblatt] München, Germany: EOS GmbH.

Hibbeler, R. C., 2005. Technische Mechanik. 1. Statik. 10. Auflage. München, Germany: Pearson.

Hibbeler, R. C., 2006a. Technische Mechanik. 2. Festigkeitslehre. 5. Auflage. München, Germany: Pearson.

Hibbeler, R. C., 2006b. Technische Mechanik. 3. Dynamik. 10. Auflage. München, Germany: Pearson.

HobbyKing, 2015. MultiWii 328P Flight Controller w/FTDI DSM2 Comp. Port. [Online] Verfügbar unter: <http://www.hobbyking.com/hobbyking/store/__27033__MultiWii_328P_Flight_Controller_w_FTDI_DSM2_Port.html> (http://www.hobbyking.com/hobbyking/store/__27033__MultiWii_328P_Flight_Controller_w_FTDI_DSM2_Port.html) [Zugang am 19.01.2015].

Parrot Public Company, 2015. Parrot Minidrones Rolling Spider. [Online] Verfügbar unter: <http: //www.parrot.com/de/produkte/rolling-spider/> [Zugang am 19.01.2015].

Shenzhen Hubsan Technology Company Limited, 2015. Hubsan X4 Cemare. [Online] Verfügbar unter: <http://www.hubsan.com/productinfo_16.html> [Zugang am 17.01.2015].

Zach, F., 2010. Leistungselektronik. 4. Auflage. Berlin, Germany: Springer.

# Abbildungsverzeichnis

Abbildung 2. Basis in der ersten Version mit einem Ein-Euro-Stück als Größenvergleich 5 Abbildung 3. Motorhalterung in der ersten Version mit einem Ein-Euro-Stück als Grö-

Abbildung 4. Basis in der zweiten Version mit einem Ein-Euro-Stück als Größenvergleich 7 Abbildung 5. Benötigte Motorspannung zum schweben in der Luft bei gegebenem Gewicht der Drohne. Die strichpunktierte Linie markiert das Gewicht der FH-Technikum Wien Drohne. Die gestrichelte Linie markiert die halbe Versorgungsspannung. Abgeleitet aus Gleichung 4. Die Dichte der Luft wurde mit 1,233 kg m⁻³ angenommen, die restlichen Parameter sind dem Text zu

Abbildung 6. Geschwindigkeitsverlauf über die Zeit entgegen der Erdbeschleunigung bei maximaler Motorspannung in Abhängigkeit vom Gewicht der Drohne. Verwendet wurde Gleichung 8; der Luftwiderstand wurde vernachlässigt. . 10 Abbildung 7. Endgeschwindigkeit entgegen der Erdbeschleunigung bei verschiedenen Motorspannungen in Abhängigkeit vom Gewicht der Drohne. Verwendet

Abbildung 10. Übersicht über die Systemkomponenten der FHTW-Drohne für Schwam-

Abbildung 11. FC mit den benötigten Verbindungen in Grün und einer vorzunehmenden

Abbildung 14. I

Abbildung 16. Übertragungsfunktion der Treiberstufe in Blau auf ein PWM-Signal in Gelb

Abbildung 18. Übertragungsfunktion der Treiberstufe in Blau auf ein PWM-Signal in Gelb

# Tabellenverzeichnis

Tabelle 1. Materialdaten des Werkstoffes EOSINT P/PA2200 (Quelle: (EOS GmbH, 2014)) 7 Tabelle 2. Hilfstabelle zur Berechnung des Flächenträgheitsmoment des Motorauslegers. 12

# Abkürzungsverzeichnis

FC Flight-Controller

I

2C | Inter-Integrated Circuit
ISP | In-System Programming
LiPo | Lithium-Polymer

MOSFET Metall-Oxid-Halbleiter-Feldeffekttransistor

PWM | Pulsweitenmodulation
UAV | Unmanned Aerial Vehicle

# A. Anhang

Im Anhang findet man folgende Daten.

## A.1. CAD-Daten

Die CAD-Daten der gezeichneten Bauteile umfassen:

- Version 1
– Basis
– Motorhalterung
- Version 2 – Kombinierte Basis mit Motorhalterung

## A.2. Quellcode

Der gesamte Quellcode der verwendeten MultiWii-Steuerung, des Arduino-Programmes und der Steuerungs-App.

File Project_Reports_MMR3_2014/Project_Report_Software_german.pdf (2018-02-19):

# PROJEKTBERICHT

## Im Studiengang Mechatronik/Robotik

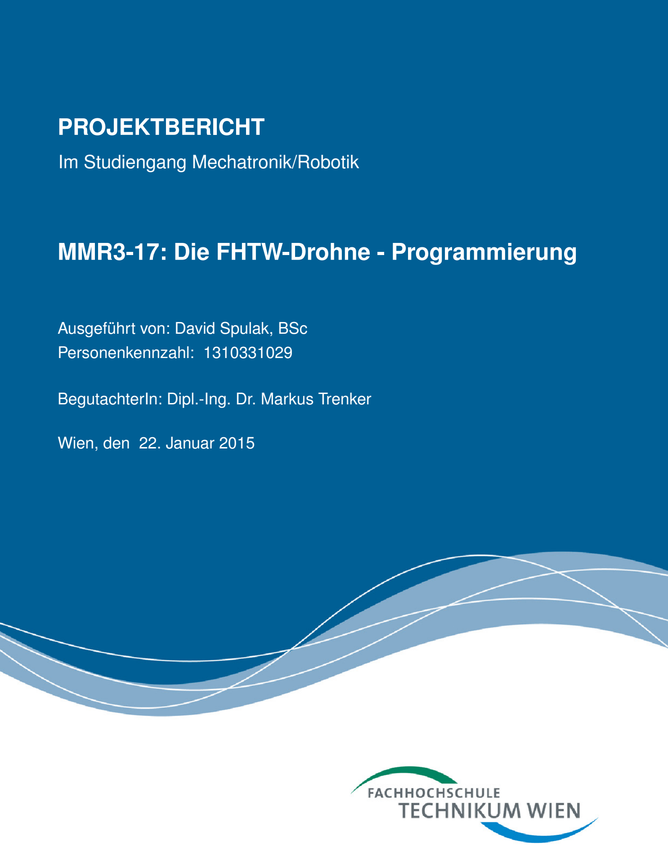
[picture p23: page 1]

# MMR3-17: Die FHTW-Drohne - Programmierung

## Ausgeführt von: David Spulak, BSc

## Personenkennzahl: 1310331029

## BegutachterIn: Dipl.-Ing. Dr. Markus Trenker

## Wien, den 22. Januar 2015

# Kurzfassung

Auf Grund ihrer Stabilität und Manövrierfähigkeit sind Multicopter an der Spitze der Drohnentechnologie. Sie finden einen breiten Einsatzbereich in vielen verschiedenen Industrien, wie der Film- und Spielwarenindustrie aber auch in der Überwachungs- und Militärtechnik. Eine

Multicopter-Drohne kann Studenten der FH-Technikum Wien eine herausragende Möglichkeit geben mit einem durch und durch mechatronischen System zu arbeiten und Eröffnet auch den Einstieg in das noch sehr junge Forschungsfeld der Schwarmrobotik.
Die meisten individuellen elektronischen Teile, die zum Erstellen einer Multicopter-Drohne notwendig sind, sind kommerziell erhältlich. Das Know-How zum Bau einer solchen Drohne ist zwar in der Modellbaugemeinschaft vorhanden, für Neulinge und Amateure in diesem Bereich jedoch nur schwer zugänglich. Um diese Wissensdiskrepanz zu schließen wurde im Zuge des Projektes, in dem diese Arbeit entstanden ist, eine Quadcopter-Drohne erstellt, die mit Hilfe einer Smartphone-Applikation gesteuert werden kann. In dieser Arbeit wird die Systemarchitektur der Drohne und die Programmierung der einzelnen Teile vorgestellt, die eine Drohnensteuerung über eine Handyapplikation zulassen. Gezeigt wurde die Einsetzbarkeit dieser Systemarchitektur an einem Prototypen der FHTW-Drohne, der in Laborbedingungen erfolgreich getestet werden konnte.

Schlagworte: Drohne, Quadcopter, Smartphone-Applikation, Steuerung

# Inhaltsverzeichnis

1 Einleitung | 1
2 Stand der Technik | 1
3 Die FHTW-Drohne | 5
4 Programmierung | 10
5 Resultate | 27

6 Zusammenfassung und Ausblick | 28
Literaturverzeichnis | 30
Abbildungsverzeichnis | 32
Tabellenverzeichnis | 33
Quellcodeverzeichnis | 34
Abkürzungsverzeichnis | 35

# 1 Einleitung

Unter einer Drohne versteht man im allgemeinen ein unbemanntes Luftfahrzeug, das entweder autonom, semiautonom oder teleoperiert gesteuert wird. In der heutigen Welt finden Drohnen in einer Vielzahl von Bereichen bereits ein Einsatzgebiet. Die derzeit bekanntesten sind wohl die

- Militärtechnik,
- Filmtechnik und
- Spielwarenindustrie.

Im Ganzen stellt eine Flugdrohne eine Kombination aus einer Vielfalt an technischen Disziplinen dar, die Mechanik, Elektrotechnik, Steuerungstechnik und Informatik zu einem durch und durch mechatronischen Gerät vereint. In diesem Sinne ist eine Flugdrohne nicht nur ein valides Mittel Studenten des Studienganges Mechatronik/Robotik das enge Zusammenspiel verschiedener, technisch herausfordernder Gebiete näher zu bringen, sondern auch ein Prestigeobjekt mit dem der Studiengang selbst vermarktet werden kann.
In folgendem Projekt wurden erste Schritt in Richtung eines FH Technikum Wien Drohnen Bausatz gesetzt, der es schlussendlich ermöglichen soll die Drohnentechnologie einer breiten Masse an Studierenden zugänglich zu machen. Dem großen und stetig steigende Anteil an Smartphonebesitzern soll es ermöglicht werden, eine kostengünstige Drohne mit Hilfe ihres Telefons über Bluetooth zu steuern. Zusätzlich kann neben dem Werbeeffekt der für die FH durch eine solche Entwicklung und das damit verbundene Know-How entsteht auch das Forschungsgebiet der FH erweitert werden. Schwarmrobotik ist ein vielseitiges Forschungsfeld, welches, gerade im Gebiet der Flugdrohnen, noch großen Neuheitscharakter aufweist. Gerade ein kostengünstiges Fluggerät ist ein wichtiger Grundstein für jegliche Forschungs- und Projektarbeit in dieser Richtung.
Im Zuge des Projektes, innerhalb dessen diese Arbeit entstanden ist, wurde ein Prototyp für eine Mini-Drohne entwickelt (im Folgenden als FHTW-Drohne bezeichnet), die mit Hilfe einer Smartphone-Applikation steuerbar ist. Diese Arbeit beschäftigt sich speziell mit der Programmierung einzelner Komponenten, die beim Bau dieser Drohne genutzt wurden. Für Details im Bereich der Mechanik und Elektronik, die auch Teil dieses Projektes waren sei auf die Arbeit meines Kollegen, Herrn Otrebski, verwiesen.

# 2 Stand der Technik

Im Folgenden wird ein kurzer Überblick über den derzeitigen Stand der Technik im Bereich

Multicopter und Mulitcoptersteuerung gegeben.

## 2.1 Multicopter

Drohnen in Form von Multicoptern sind heutzutage aus der Welt des Modellbaues nicht mehr weg zu denken. Seit wenigen Jahren boomt der Einsatz von Flugdrohnen im professionellen Filmbereich. Firmen wie campilots GmbH (2014) und DIGICOPTER

R Luftaufnahmen & Videoproduktion (2014) zeigen wie vielfältig der Anwendungsbereich dieser stabilen Fluggeräte sein kann und wie alte Methoden für Luftfilmaufnahmen durch moderne Technik flexibler und kostengünstiger gestaltet werden können und diese nach und nach ersetzen. Ein weiteres Beispiel für den kreativen Einsatz von Multicoptertechnologie ist das Projekt Spaxels (Ars Electronica Linz GmbH, 2014). In diesem wird ein mit LEDs ausgerüsteter Quadcopterschwarm genutzt, um dynamische, dreidimensionale Figuren im Nachthimmel zu aufzubauen. Auch in der Spielzeugindustrie haben vor allem Quadcopter, auf Grund ihrer robusten Flugeigenschaften Einzug gehalten. Mittlerweile sind Multicopter nicht nur noch Modellbauern mit langjähriger Erfahrung in diesem Bereich vorenthalten, sondern auch in allen Größen und Formen auch im Spielwarenhandel erhältlich. Im Zusammenhang mit dem hier durchgeführten Projekt sind vor allem die kleineren Bauformen der Spielwarenindustrie von Interesse und sollen im Weiteren etwas genauer unter die Lupe genommen werden. Ein bezeichnendes Beispiel derartiger Geräte soll hier vorgestellt werden.

## 2.1.1 Hubsan X4 Drohne

Die chinesische Firma Hubsan bietet eine Quadcopter Drohne an, die mit Hilfe einer Fernsteuerung bedient wird (Shenzhen Hubsan Technology Company Limited, 2015). Hierbei handelt es sich um eine ca. Handteller großen Drohne die für einen Preis von ca. 40 EUR erhältlich ist (Amazon Europe Core S.à r.l., 2015).
Weitere technische Details zu dieser Drohne, die im Internet recherchiert wurden können in Tabelle 1 eingesehen werden (Shenzhen Hubsan Technology Company Limited, 2015; Amazon Europe Core S.à r.l., 2015).

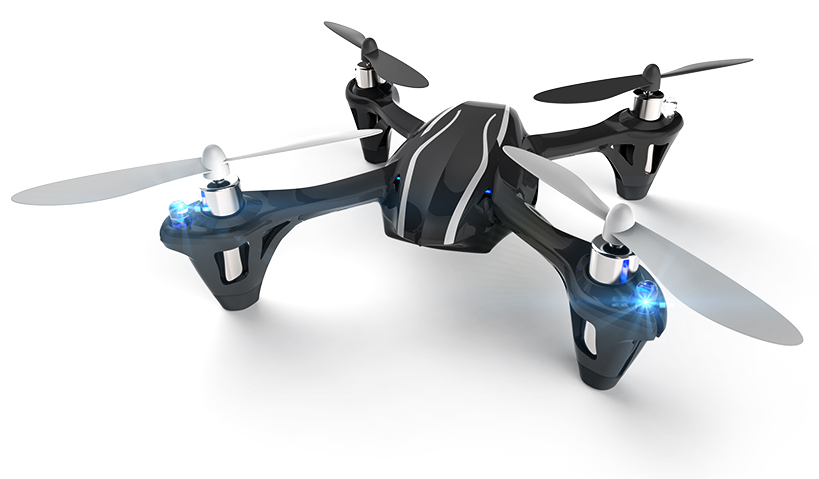
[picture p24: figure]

Abbildung 1: Hubsan X4 Drohne (Quelle: modifiziert übernommen aus Shenzhen Hubsan Technology Company Limited (2015))

Gewicht | 39 g
Stromversorgung | 240 mAh LiPo-Akku
Verbrauchsspannung | 3,7 V
Ladezeit | 30 min
Flugzeit | 9 min
Mittlere Reichweite | 100 m
Antrieb | 4 DC-Motoren ohne Eisenkern. Diese sind eine spezielle Form des Permanentmagnet DC-Motors, welche in Richtung schneller Beschleunigung und hoher Drehzahlen optimiert ist.
Regelung/Stabilisierung | 6-Achs Flight-Control System mit verstellbarer Gyroskopsen-sitivität

Tabelle 1: Technische Details zur Hubsan X4 Drohne

## 2.2 Multicoptersteuerung

Innerhalb dieses Projektes eine eigene Regelung zur Stabilisierung der zu erstellenden Drohne zu entwerfen und programmieren würde den Workload dieses Projektes weit überschreiten. Es gibt bereits zahlreiche Platinen, die eine entsprechende Fluggerätstabilisierung bieten, bzw. open source Softwareprojekte, in die bereits unzählige Stunden von Know-How geflossen sind um eine derartige Stabilisierung dem Endnutzer anzubieten. Drei derartige Produkte sollen hier kurz vorgestellt werden.

## 2.2.1 Hobbyking - KK2.0 Multi-rotor LCD Flight Control Board

Das Flugsteuerungsbord KK2.0 für Multirotor Fluggeräte ist ein weitverbreitetes Regelungsbord zur Flugstabilisierung. Mit Hilfe eines LCD Bildschirmes können alle notwendigen Einstellungen am Bord selbst vorgenommen werden und macht dessen Nutzung auch für Einsteiger angenehm. Somit können alle Regelparameter und Fluggerätkonfigurationen bequem auch ohne einen Computer gemacht werden. Auf Grund des Bildschirmes ergibt sich für dieses Bord ein etwas höheres Gewicht, verglichen mit Konkurrenzprodukten von 21g (hobbyking.com

R
, 2015a).
Mit Hilfe des Bordes können bis zu acht Motoren angesteuert werden und ermöglicht durch die vorinstallierte Firmware das Steuern von Dualcopter, Tricoptern über Quadcopter bis hin zu Octocoptern in allen erdenklichen Konfigurationen. Das Bord ist dafür ausgelegt bürstenlose Motoren anzusteuern.
Bei dem verbauten Microchip handelt es sich um einen ATmega324-PA und ermöglicht das updaten der Firmware über das USBasp AVR Programming interface. Es ist außerdem mit einem dreiachsigen Gyroskopchip und einem dreiachsigen Beschleunigungssensorchip ausgestattet, was der Bordsensorik sechs Freiheitsgrade gibt.

## 2.2.2 Die MultiWii Software

Bei der MultiWii Software handelt es sich um ein Open-Source Projekt zur Steuerung von Funkgesteuerten Fluggeräten. Ursprünglich war die Software auf die in der Nitendo Wii Konsolensteuerung verbauten Gyroskope und Beschleunigungssensoren ausgelegt und wurde auf der Arduino Plattform entwickelt (Dubus, 2015). Mittlerweile werden jedoch schon eine Vielzahl weiterer Gyroskop- und Beschleunigungschips unterstützt was zur Entwicklung von Flight Controller Bords unterschiedlichster Hersteller geführt hat, die auf die MultiWii Software zurückgreifen.

Flyduino - NanoWii ATmega32u4 Based MultiWii FC

Die Firma Flyduino wurde 2011 gegründet und bietet elektronische Komponenten zur Multicoptersteuerung herstellt. Die von Flyduino angebotenen Flight Controller entwickelten sich in enger Zusammenarbeit mit der MultiWii Community und viele Produkte greifen auch heute noch auf diese Software zur Flugstabilisierung zurück (Bake, 2015).
Das Produkt NanoWii ist ein Controler Board auf Basis des ATmega32u4 Prozessors und verfügt über den MPU-6050 Chip, der ein 3-Achsen Gyroskop und einen 3-Achsen Beschleunigungssensor kombiniert. Auch dieses Bord ermöglicht das Ansteuern von acht Motoren und die Steuerung von Dual- bis zu Octocoptern in vielen unterschiedlichen Konfigurationen. Im Falle dieses Controllers kann auf den Source-Code zugegriffen und wenn notwendig Veränderungen vorgenommen werden, was den Einsatz von bürstenlosen Motoren ermöglicht. Über einen seri-

ellen Port ist zusätzlich auch ein Bluetoothmodul zur Kommunikation mit dem Board einsetzbar und über eine I2C Schnittstelle kann weitere unterstützende Sensorik angeschlossen werden. Des Weiteren hantelt es sich hierbei um einen sehr kleinen, leichten Controller, der ohne Pins nur 4g auf die Waage bringt.

HobbyKing - MultiWii 328P Flight Controller w/FTDI & DSM2 Port

Einen vergleichbaren Flight Controller wird vom Hersteller HobbyKing, auf Basis des ATmega328P Microcontrollers, angeboten. Er ist mit Beschleunigungssensoren einem 3-Achsen Gyroskop einem Magnetometer und einem Barometer ausgestattet. Das Gewicht des Bordes beträgt 13.9g (hobbyking.com

R
, 2015b).
Auch an dieses Bord kann ein Bluetoothmodul zur Kommunikation und zusätzliche Sensorik über eine I2C Schnittstelle angeschlossen werden. Auch dieses Bord nutzt die MultiWii Software und kann ebenfalls bis zu acht Motoren ansteuern.

# 3 Die FHTW-Drohne

Im Folgenden soll kurz der Aufbau Drohne dargestellt werden, welche im Zuge dieses Projektes erstellten. Zuerst soll hier die Systemarchitektur vorgestellt und anschließend die ausgewählten Teilkomponenten kurz beschrieben werden. Zuletzt werden noch kurz die verschiedenen Methoden zur Datenübertragung, die innerhalb dieses Projektes verwendet wurden beschrieben.

## 3.1 Systemarchitektur

Die Systemarchitektur der FHTW-Drohne kann in Abbildung 2 eingesehen werden. Es wurde hierbei großen Wert auf die Modularität der einzelnen Komponenten gelegt. Dies soll einen einfachere Erweiterung des Systems für den Einsatz in der Schwarmrobotik ermöglichen. Die Eingabe der Steuerbefehle erfolgt vom Nutzer über eine Smartphone-Applikation, die die Befehle über Bluetooth zur Drohne überträgt. Ein Bluetooth-Shield übersetzt die gesen-

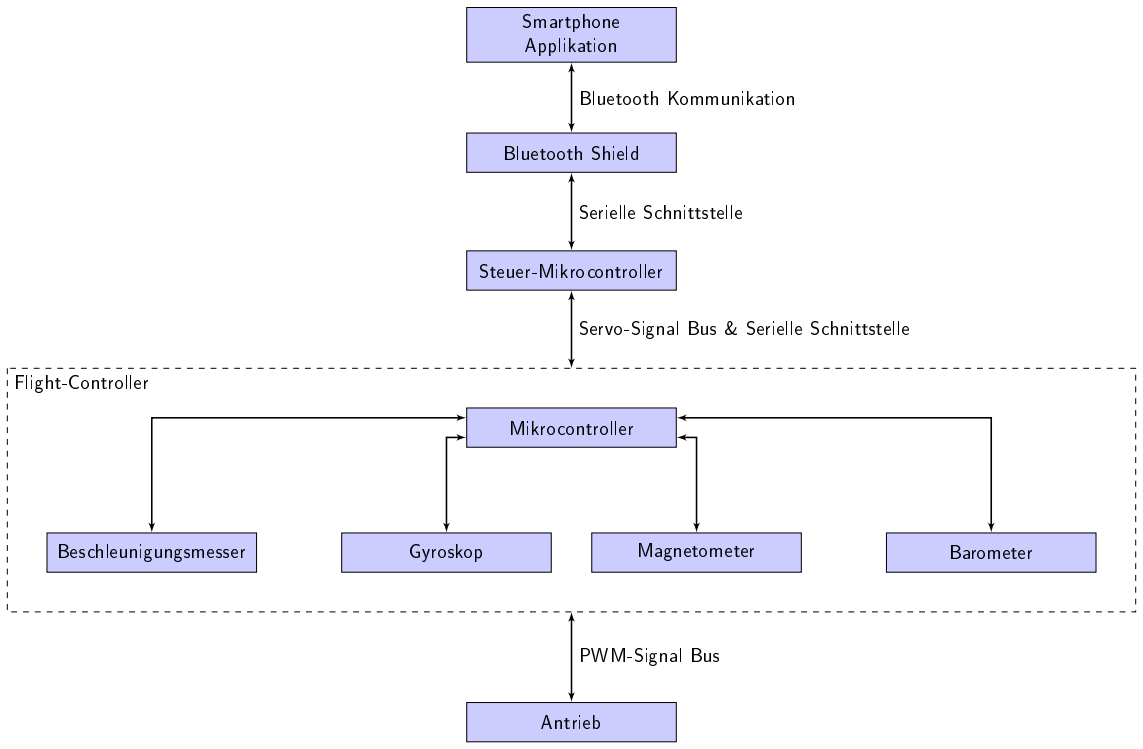
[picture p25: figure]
Mikrocontroller; Steuer-Mikrocontroller; Bluetooth Shield; Smartphone Applikation; Beschleunigungsmesser; Gyroskop; Magnetometer; Barometer; Flight-Controller; Antrieb; Servo-Signal Bus & Serielle Schnittstelle; Serielle Schnittstelle; Bluetooth Kommunikation; PWM-Signal Bus

Abbildung 2: Systemarchitektur der FHTW-Drohne

deten Bluetoothsignale in serielle Datenübertragung und übermittelt diese so dem Steuer-Mikrocontroller. Dieser liest schließlich die vom Nutzer eingegebenen Steuerbefehle aus und generiert dazu passende Servosignale, die dem Flight-Controller als Steuereingaben dienen. Gesteuert können die Drehzahl der Rotoren werden (Throttle) und die Orientierung der Drohne. Hierbei wird ein in der Luftfahrttechnik gebräuchliches Koordinatensystem benutzt. Die Roll-Achse zeigt dabei in Flugrichtung, die Pitch-Achse zur Seite und die Yaw-Achse senkrecht nach oben, vom Fluggerät aus gesehen. Durch das Einstellen der Drehungen um diese Achsen (Roll, Pitch, Yaw) kann Flugrichtung der Drohne beeinflusst werden.
Zentrum der Drohnenarchitektur ist ein Flight-Controller (FC), der mit Hilfe von diverser Sensorik (Beschleunigungssensor, Gyroskop, Magnetometer und Barometer) für die Stabilisierung der Drohne im Flug sorgt und die Steuerbefehle in die entsprechende Drohnenbewegung umsetzt. Dazu steuert er die Motoren über einen PWM-Signal Bus an und gibt damit deren Drehzahl vor.
Zusätzlich ist eine serielle Kommunikation vom Steuer-Mikrocontroller mit dem FC und dessen Sensorik möglich. Damit können alle Sensordaten, die der FC verarbeitet auch für etwaige, in der Zukunft erstellte, Drohnenintelligenzen genutzt werden. Des Weiteren kann weitere Peripherie mit Hilfe des I²C Kommunikationsprotokolls an den Steuer-Mikrocontroller angeschlos-

sen werden. Dieser modulare Aufbau soll eine einfache Umsetzung von zukünftigem, autonomen Flugverhaltens garantieren und die komplizierten Steuerungsroutinen im FC unangetastet

lassen.

## 3.2 Ausgewählte Komponenten

In Abbildung 2 wurde die Systemzusammensetzung der FHTW-Drohne gezeigt. Im Folgenden werden die ausgewählten Systemkomponenten kurz vorgestellt.
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

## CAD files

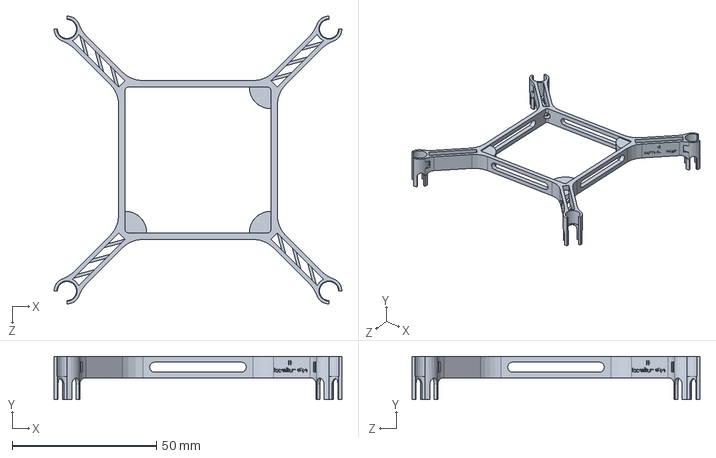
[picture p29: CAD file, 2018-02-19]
CAD-Data/Base.SLDPRT
99.9 x 15.0 x 99.9 mm

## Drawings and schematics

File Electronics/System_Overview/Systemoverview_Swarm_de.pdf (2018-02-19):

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

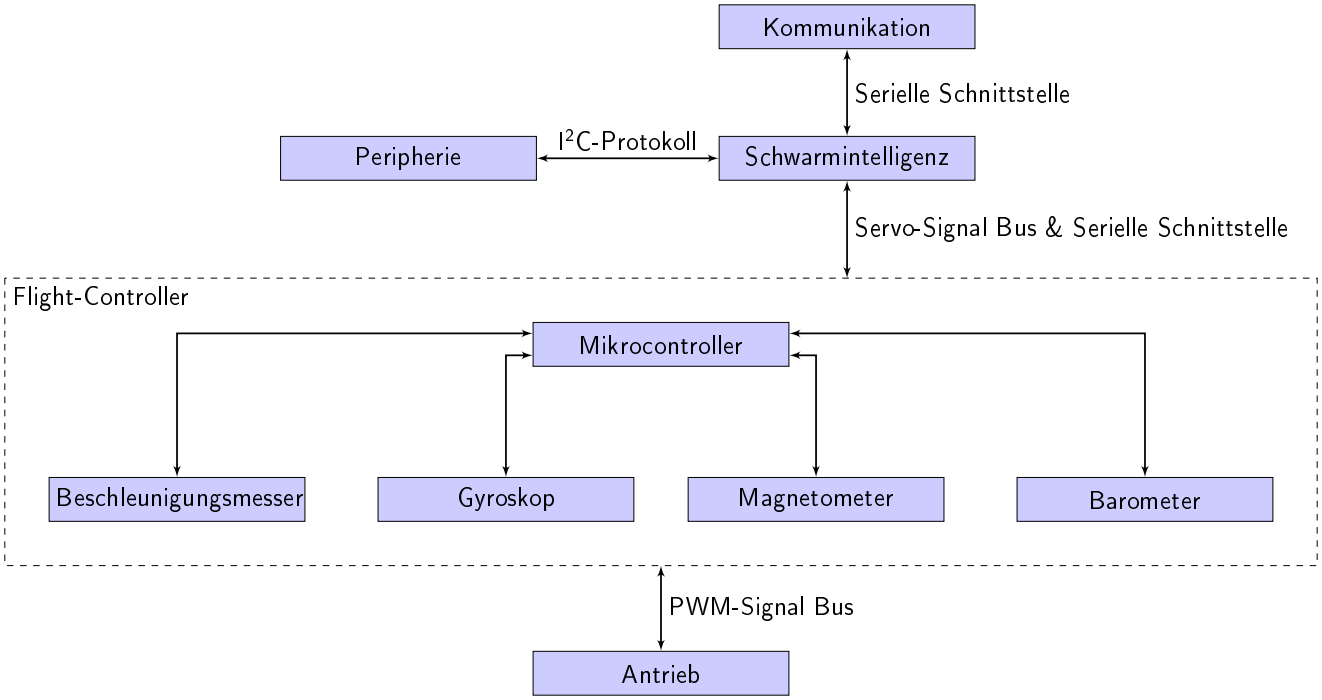
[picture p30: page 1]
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

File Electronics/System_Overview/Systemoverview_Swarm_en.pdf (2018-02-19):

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

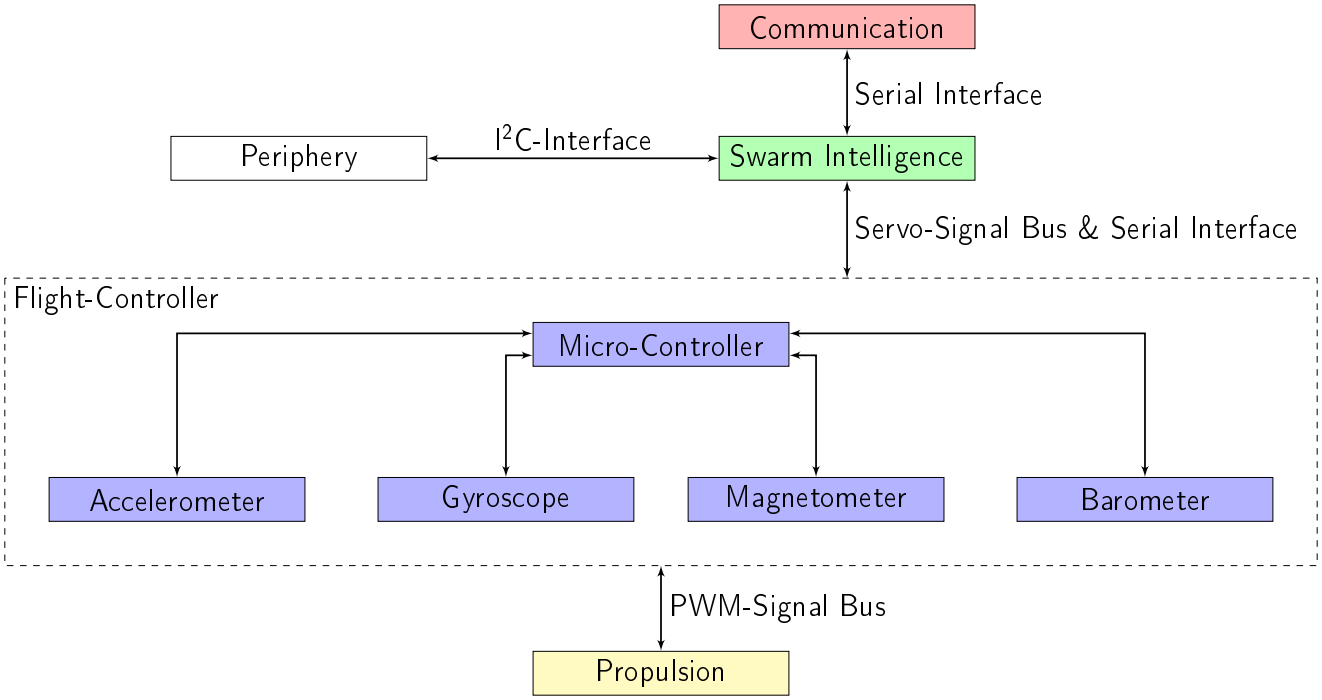
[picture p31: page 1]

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

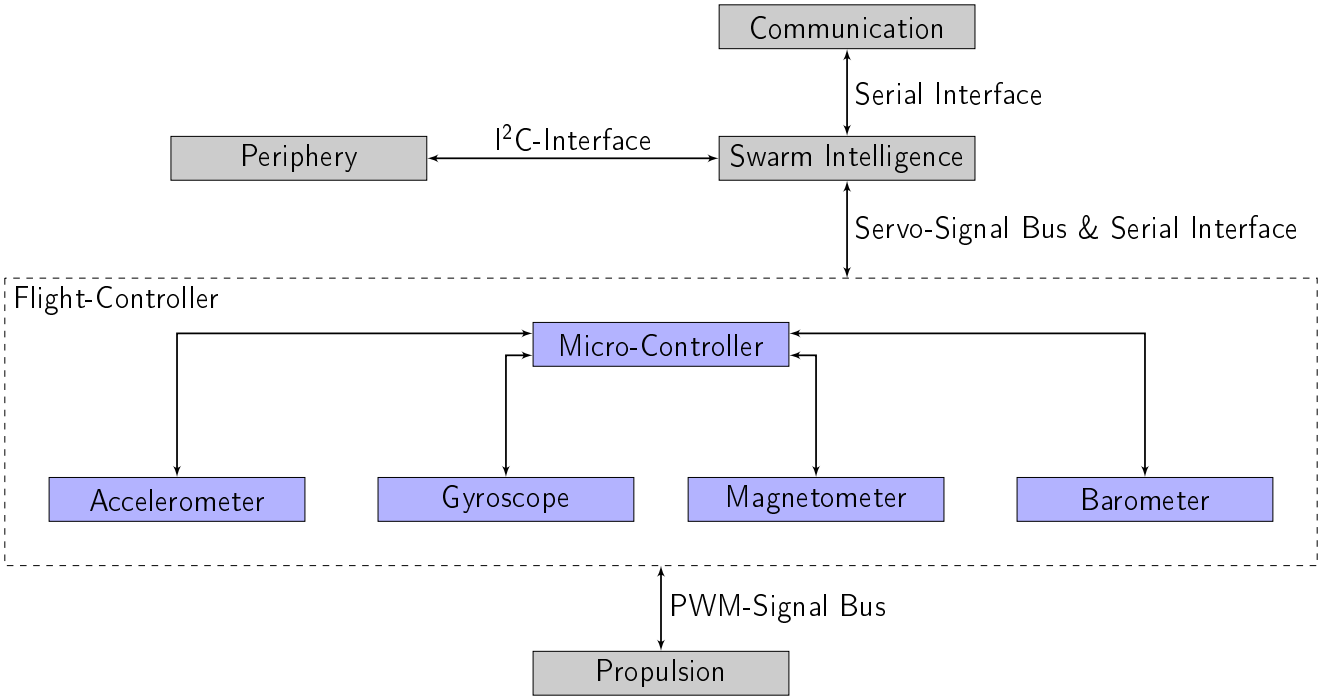
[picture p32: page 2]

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

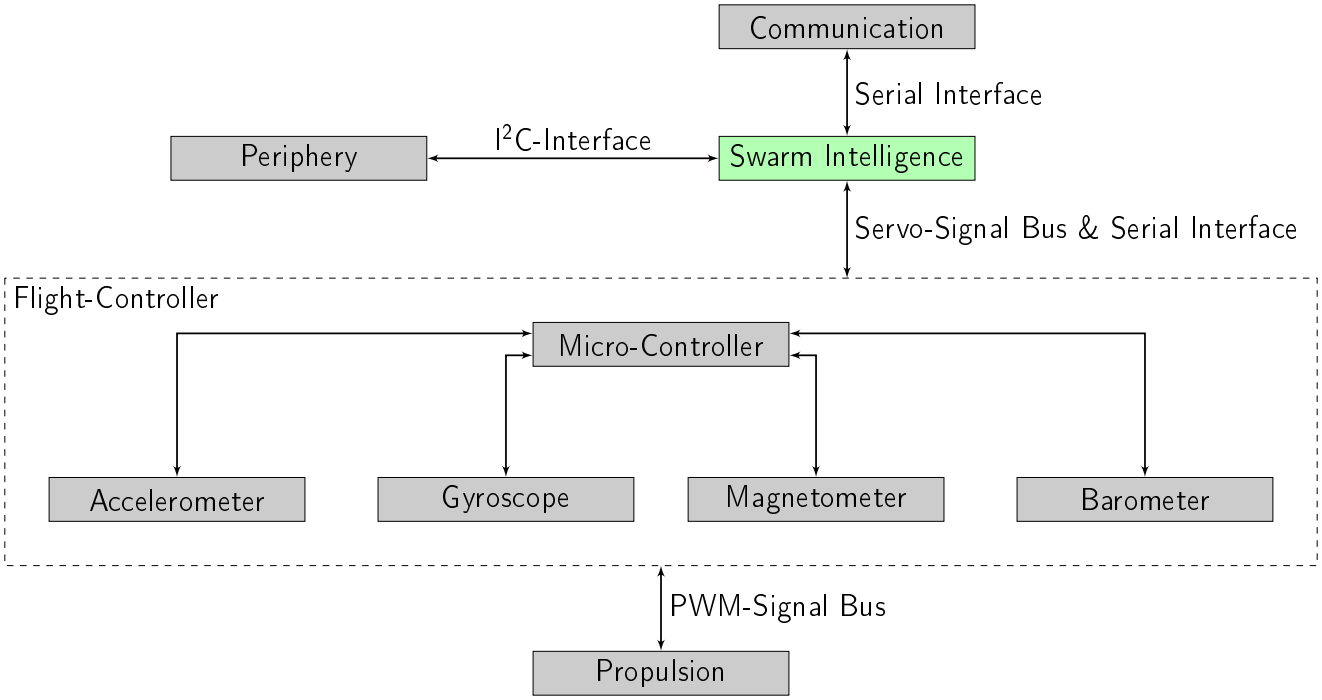
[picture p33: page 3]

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

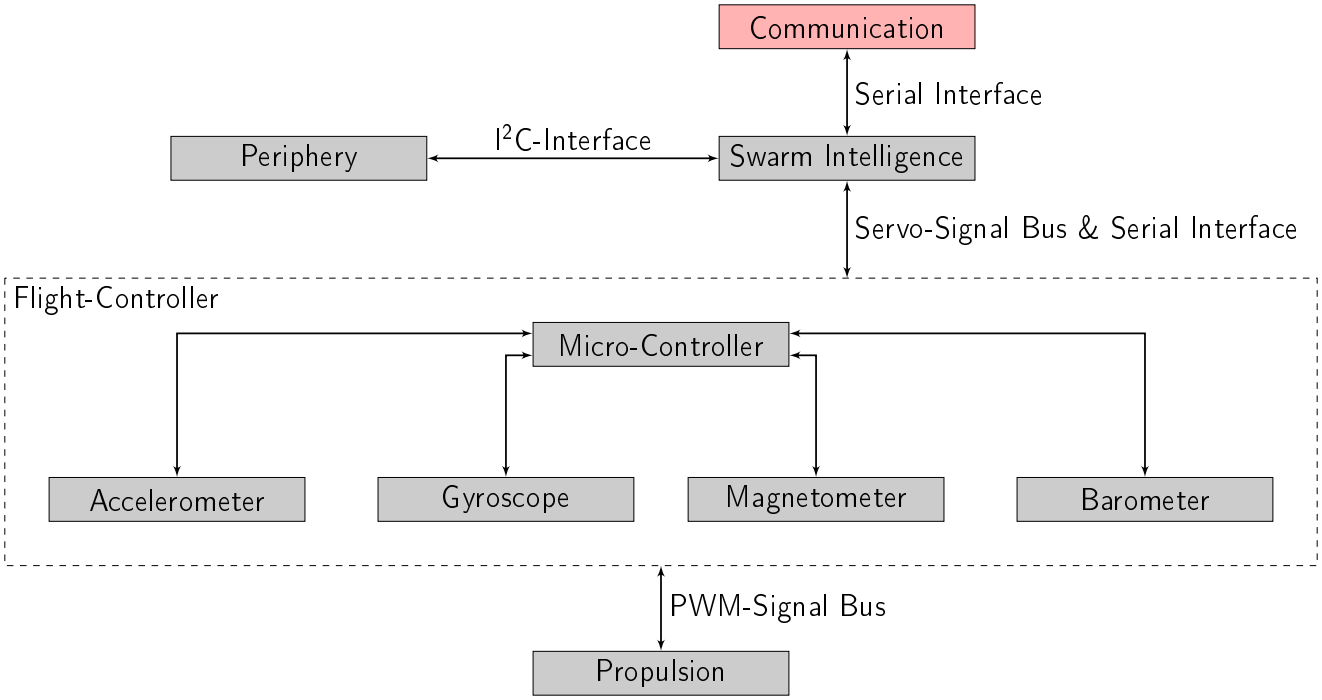
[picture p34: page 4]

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

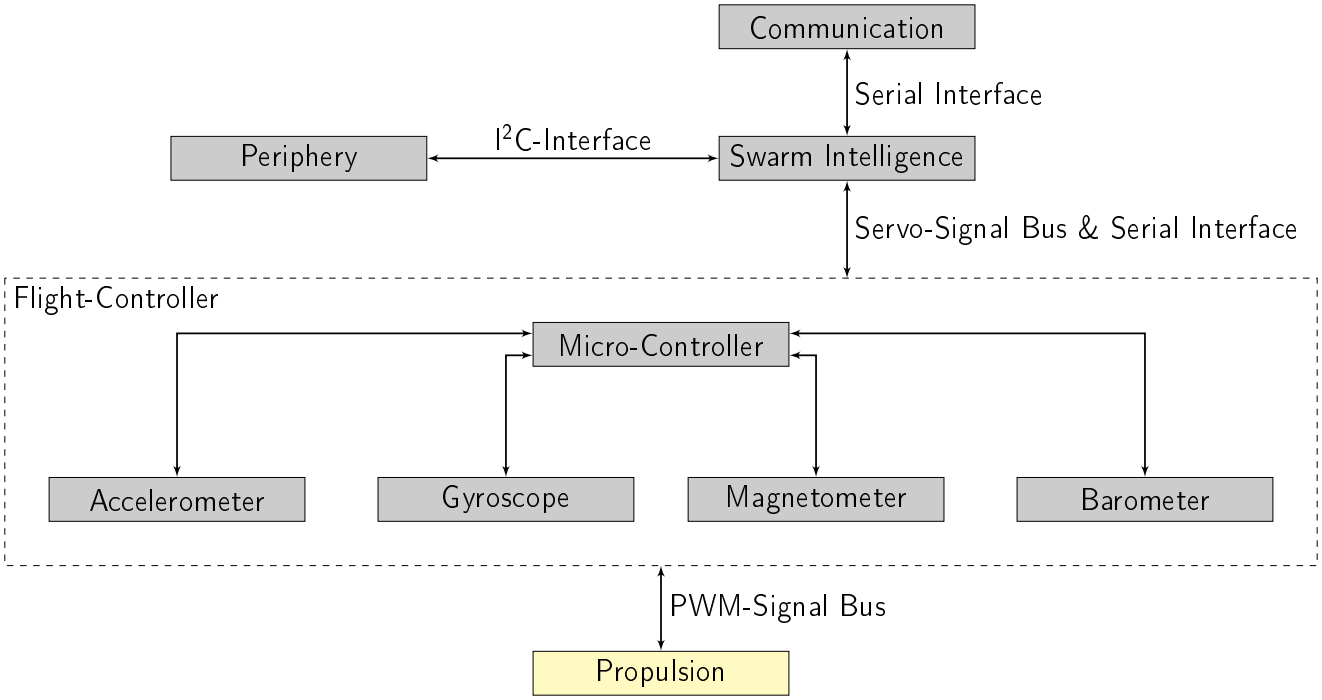
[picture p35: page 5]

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

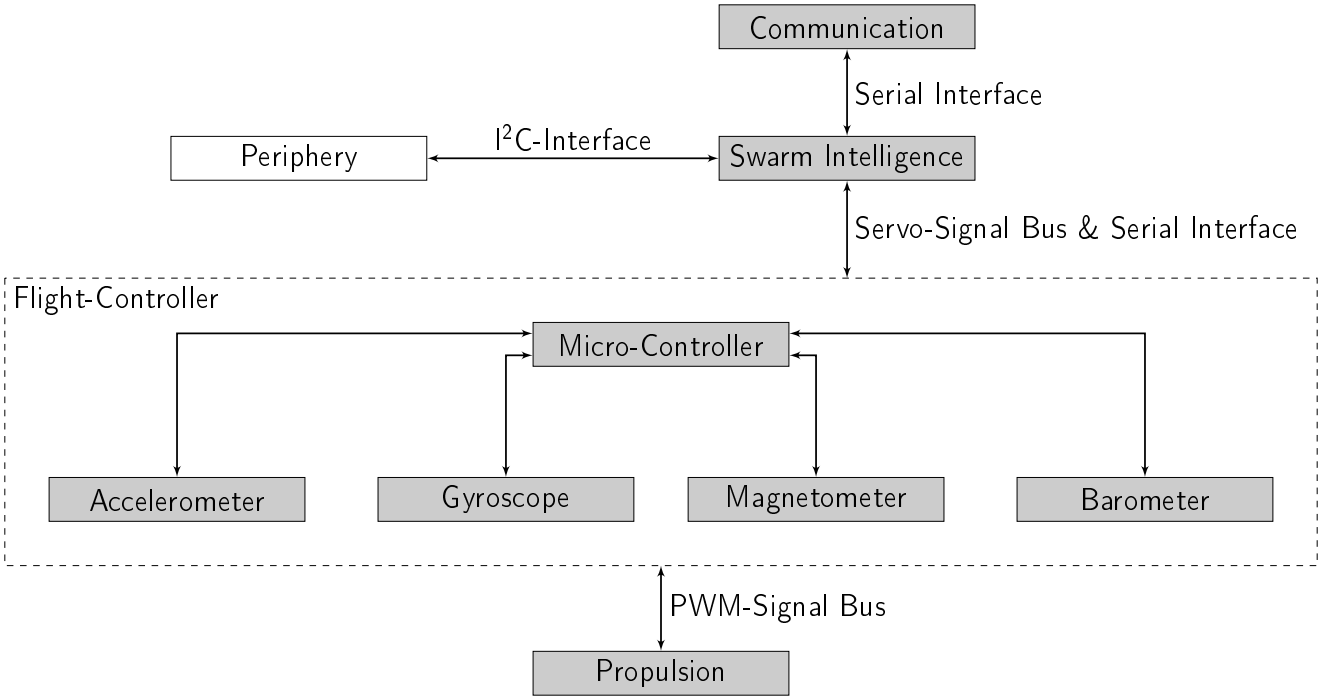
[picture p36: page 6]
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

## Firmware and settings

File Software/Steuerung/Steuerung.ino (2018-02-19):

/*
  Arduino-Programm der FHTW-Drohne
*/

/*
**  Bibliotheken
*/
#include<Servo.h>

#define THROTTLE 1
#define ROLL 2
#define PITCH 3
#define YAW 4

#define ARM 11
#define DISARM 12
#define HOLD_ON 13
#define HOLD_OFF 14

#define START_CMD_CHAR '*'

/*
**  Pinbelegung
**  Throttle  Arduino-Pin  3
**  Roll      Arduino-Pin  6
**  Pitch     Arduino-Pin  7
**  Yaw       Arduino-Pin  9
**  Aux1      Arduino-Pin 10
**  Aux2      Arduino-Pin 11
**  Bluetooth-Modul Rx(0), Tx(1) als Serial1
*/
unsigned int Pin_Throttle=3;
/*
**  Beschreibung Throttle
**  Gas
*/
unsigned int Pin_R=6;
unsigned int Pin_P=7;
unsigned int Pin_Y=9;
/*
**  Beschreibung R/P/Y
**  Lenkwinkel der Drohne
*/
unsigned int Pin_Aux_1=10;
/*
**  Beschreibung Aux1
**  Einschalten des Altitude Hold Modus
*/
unsigned int Pin_Aux_2=11;
/*
**  Beschreibung Aux2
**  Armen der Motoren
*/
int tmp=-1;

int min_width=1000;
int max_width=2000;

Servo ServoT, ServoR, ServoP, ServoY, ServoA1, ServoA2;


void setup(void)
{
  /**
    * Initialisierung der Servosignale zur Steuerung des FC
    */
  ServoT.attach(Pin_Throttle, min_width,max_width);
  ServoR.attach(Pin_R, min_width,max_width);
  ServoP.attach(Pin_P, min_width,max_width);
  ServoY.attach(Pin_Y, min_width,max_width);
  ServoA1.attach(Pin_Aux_1, min_width,max_width);
  ServoA2.attach(Pin_Aux_2, min_width,max_width);
  ServoT.write(0);
  ServoR.write(90);
  ServoP.write(90);
  ServoY.write(90);
  ServoA1.write(0);
  ServoA2.write(0);
  analogWrite(13,13);

  Serial1.begin(9600);
}
void loop(void)
{
  int command = 0;
  int value = 0;
  char get_char = '\0';
  
  // wiat for incoming data
  if(Serial1.available() < 1) return;
  
  // parse incoming command
  get_char = (char)Serial1.read();
  if (get_char != START_CMD_CHAR) return;
  
  // parse incoming command type
  command = Serial1.parseInt(); // read command

  // parse incoming command value
  value = Serial1.parseInt();
  
  // FOLLOW THE COMMAND
  switch(command) {
    case THROTTLE:
      Throttle(value);
      break;
    case ROLL:
      Roll(value);
      break;
    case PITCH:
      Pitch(value);
      break;
    case YAW:
      Yaw(value);
      break;
    case ARM:
      Arm();
      break;
    case DISARM:
      Disarm();
      break;
    case HOLD_ON:
      Hold(true);
      break;
    case HOLD_OFF:
      Hold(false);
      break;
  }
}

void HelpMsg(void)
{
  Serial.println("Steuerung der FHTW-Drohne");
  Serial.println("Befehle");
  Serial.println("Help\tDiese Nachricht");
  Serial.println("Hilfe\tDiese Nachricht");
  Serial.println("ARM\tArmen des Quadcopters");
  Serial.println("DISARM\tDisrmen des Quadcopters");
  Serial.println("HOLD ON\tAktuelle Hoehe halten");
  Serial.println("HOLD OFF\tAktuelle Hoehe nicht mehr halten");
}
void Arm(void)
{
  Serial.println("Arming...");
  Serial.println("Throttle must be 0!");
  Throttle(0);
  if(0==ServoA2.read())
    ServoA2.write(180);
  analogWrite(13,255);
}
void Disarm(void)
{
  Serial.println("Disarming...");
  if(180==ServoA2.read())
    ServoA2.write(0);
  analogWrite(13,13);
}
void Throttle(int DC)
{
  tmp=map(DC, 0, 1000, min_width, max_width);
  Serial.print("Throttle-DC: ");
  Serial.print(DC);
  Serial.print(" Pulsweite: ");
  Serial.println(tmp);
  ServoT.writeMicroseconds(tmp);
}
void Roll(int DC)
{
  tmp=map(DC, -500, 500, min_width, max_width);
  Serial.print("Roll-DC: ");
  Serial.print(DC);
  Serial.print(" Pulsweite: ");
  Serial.println(tmp);
  ServoR.writeMicroseconds(tmp);
}
void Pitch(int DC)
{
  tmp=map(DC, -500, 500, min_width, max_width);
  Serial.print("Pitch-DC: ");
  Serial.print(DC);
  Serial.print(" Pulsweite: ");
  Serial.println(tmp);
  ServoP.writeMicroseconds(tmp);
}
void Yaw(int DC)
{
  tmp=map(DC, -500, 500, min_width, max_width);
  Serial.print("Yaw-DC: ");
  Serial.print(DC);
  Serial.print(" Pulsweite: ");
  Serial.println(tmp);
  ServoY.writeMicroseconds(tmp);
}
void Hold(boolean state)
{
  Serial.print("Altitude Hold ");
  if(state)
  {
    Serial.println("on...");
    if(0==ServoA1.read())
    {
      ServoA1.write(180);
    }
  }else
  {
    Serial.println("off...");
    if(180==ServoA1.read())
    {
      ServoA1.write(0);
    }
  }
}

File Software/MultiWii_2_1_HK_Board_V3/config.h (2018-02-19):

/*******************************************************************************/
/****           CONFIGURABLE PARAMETERS                                     ****/
/*******************************************************************************/

/* this file consists of several sections to create a working combination you must at least make your choices in section 1.
 * 1 - BASIC SETUP - you must select an option in every block. This assumes you have 4 channels connected to your board with standard ESCs and servos.
 * 2 - COPTER TYPE SPECIFIC OPTIONS - you likely want to check for options for your copter type
 * 3 - RC SYSTEM SETUP
 * 4 - ALTERNATE CPUs & BOARDS - if you have
 * 5 - ALTERNATE SETUP - select alternate RX (SBUS, PPM, etc.), alternate ESC-range, etc. here
 * 6 - OPTIONAL FEATURES - enable nice to have features here (LCD, telemetry, battery monitor etc.)
 * 7 - TUNING & DEVELOPER - if you know what you are doing; you have been warned
 */
/*******************************************************************************/
/*****************                                               ***************/
/****************  SECTION  1 - BASIC SETUP                              *******/
/*****************                                               ***************/
/*******************************************************************************/
  /**************************    The type of multicopter    ********************/
    //#define GIMBAL
    //#define BI
    //#define TRI
    //#define QUADP
#define QUADX
    //#define Y4
    //#define Y6
    //#define HEX6
    //#define HEX6X
    //#define OCTOX8
    //#define OCTOFLATP
    //#define OCTOFLATX
    //#define FLYING_WING
    //#define VTAIL4
    //#define AIRPLANE
    //#define SINGLECOPTER
    //#define DUALCOPTER
    //#define HELI_120_CCPM
    //#define HELI_90_DEG
  /****************************    Motor minthrottle    ************************/
    /* Set the minimum throttle command sent to the ESC (Electronic Speed Controller) This is the minimum value that allow motors to run at a idle speed  */
    //#define MINTHROTTLE 1300 // for Turnigy Plush ESCs 10A
    //#define MINTHROTTLE 1120 // for Super Simple ESCs 10A
    //#define MINTHROTTLE 1064 // special ESC (simonk)
    //#define MINTHROTTLE 1150 // Original Value
    #define MINTHROTTLE 400 //New Value for roughly 10%-DC PWM
  /****************************    Motor maxthrottle    ************************/
    /* this is the maximum value for the ESCs at full power, this value can be increased up to 2000 */
      //#define MAXTHROTTLE 1850 // Original Value
      #define MAXTHROTTLE 2000 // New Value for roughly 100%-DC PWM
  /****************************    Mincommand          *************************/
    /* this is the value for the ESCs when they are not armed in some cases, this value must be lowered down to 900 for some specific ESCs, otherwise they failed to initiate */
      //#define MINCOMMAND  1000 // Original Value
      #define MINCOMMAND  200 // New Value for roughly 10%-DC PWM
  /**********************************    I2C speed   ***************************/
    //#define I2C_SPEED 100000L     //100kHz normal mode, this value must be used for a genuine WMP
  #define I2C_SPEED 400000L   //400kHz fast mode, it works only with some WMP clones
  /***************************    Internal i2c Pullups   ***********************/
    /* enable internal I2C pull ups (in most cases it is better to use external pullups) */
    #define INTERNAL_I2C_PULLUPS
  /*****************************************************************************/
  /**************          boards and sensor definitions            ************/
  /*****************************************************************************/
    /***************************    Combined IMU Boards    *********************/
      /* if you use a specific sensor board:
         Please submit any correction to this list.
         Note from Alex: I only own some boards, for other boards, I'm not sure, the info was gathered via rc forums, be cautious */
      //#define FFIMUv1         // first 9DOF+baro board from Jussi, with HMC5843                   <- confirmed by Alex
      //#define FFIMUv2         // second version of 9DOF+baro board from Jussi, with HMC5883       <- confirmed by Alex
      //#define FREEIMUv1       // v0.1 & v0.2 & v0.3 version of 9DOF board from Fabio
      //#define FREEIMUv03      // FreeIMU v0.3 and v0.3.1
      //#define FREEIMUv035     // FreeIMU v0.3.5 no baro
      //#define FREEIMUv035_MS  // FreeIMU v0.3.5_MS                                                <- confirmed by Alex
      #define FREEIMUv035_BMP // FreeIMU v0.3.5_BMP
      //#define FREEIMUv04      // FreeIMU v0.4 with MPU6050, HMC5883L, MS561101BA                  <- confirmed by Alex
      //#define FREEIMUv043     // same as FREEIMUv04 with final MPU6050 (with the right ACC scale)
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

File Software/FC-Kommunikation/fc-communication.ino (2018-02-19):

#include <AltSoftSerial.h>

// Software Serial
AltSoftSerial SerialS; // RX 5, TX 13

void setup() {
  Serial.begin(9600);
  SerialS.begin(115200);
}


uint8_t rc_bytes[16] = { 0 };
// The opcode (message type ID) and message length for
// the MultiWii serial protocol's "SET_RAW_RC" message type.

// Send a message using the MultiWii serial protocol.
void send_msp(uint8_t opcode, uint8_t * data, uint8_t n_bytes) {
  uint8_t checksum = 0;
   
  // Send the MSP header and message length
  SerialS.write((byte *)"$M<", 3);
  SerialS.write(n_bytes);
  checksum ^= n_bytes;
 
  // Send the op-code
  SerialS.write(opcode);
  checksum ^= opcode;
   
  // Send the data bytes
  for(int i = 0; i < n_bytes; i++) {
    SerialS.write(data[i]);
    checksum ^= data[i];
  }
   
  // Send the checksum
  SerialS.write(checksum);
}

void loop() {
  Serial.flush();

  // request data from the flight controller
  send_msp(108, 0, 0);
  
  byte txt;
  // int32_t alt = 0;
  int16_t head = 0;	// heading of the drone will be read
  int i = 0;
  
  if(SerialS.available() > 0) {
    while(SerialS.available() > 0) {
      txt = SerialS.read();
      i++;
      /*
      // ANGX
      if (i == 4) {
        Serial.print(txt, DEC);
        Serial.print("-");
      }
      if (i == 6) {
        angx += ((int)txt);
      }
      if (i == 7) {
        angx += ((int)txt)*256;
        Serial.print(angx, DEC);
        Serial.print("||");
      } 
      */
      
      // HEADING
      // message-bytes are read here
      if (i == 4) {
	// debugging output over the usb serial connection
        Serial.print(txt, DEC);
        Serial.print("-");
      }
      if (i == 10) {
        head += ((int)txt);
      }
      if (i == 11) {
        head += ((int)txt)*256;
	// debugging output over the usb serial connection
        Serial.print(head, DEC);
        Serial.print("||");
      }
/*
      // BARO
      if (i == 4) {
        Serial.print(txt, DEC);
        Serial.print("-");
      }
      if (i == 6) {
        alt += ((int)txt);
      }
      if (i == 7) {
        alt += ((int)txt)*256;
      }
      if (i == 8) {
        alt += ((int)txt)*256*256;
      }
      if (i == 9) {
        alt += ((int)txt)*256*256*256;
        Serial.print(alt, DEC);
        Serial.print("||");
      }
*/
    }
    // debugging output over the usb serial connection
    Serial.println(i, DEC);
  }
  delay(10);
}

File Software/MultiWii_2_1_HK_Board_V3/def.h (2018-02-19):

/**************************************************************************************/
/***************             test configurations                   ********************/
/**************************************************************************************/
#if COPTERTEST == 1
  #define QUADP
  #define WMP
#elif COPTERTEST == 2
  #define FLYING_WING
  #define WMP
  #define BMA020
  #define FAILSAFE
  #define LCD_CONF
  #define LCD_TEXTSTAR
#elif COPTERTEST == 3
  #define TRI
  #define FREEIMUv035_MS
  #define BUZZER
  #define VBAT
  #define POWERMETER_HARD
  #define LCD_CONF
  #define LCD_VT100
  #define LCD_TELEMETRY
  #define LCD_TELEMETRY_STEP "01245"
#elif COPTERTEST == 4
  #define QUADX
  #define CRIUS_SE
  #define SPEKTRUM 2048
  #define LED_RING
  #define GPS_SERIAL 2
#elif defined(COPTERTEST)
  #error "*** this test is not yet defined"
#endif


/**************************************************************************************/
/***************             Proc specific definitions             ********************/
/**************************************************************************************/
// Proc auto detection
#if defined(__AVR_ATmega168__) || defined(__AVR_ATmega328P__)
  #define PROMINI
#endif
#if defined(__AVR_ATmega32U4__) || defined(TEENSY20)
  #define PROMICRO
#endif
#if defined(__AVR_ATmega1280__) || defined(__AVR_ATmega1281__) || defined(__AVR_ATmega2560__) || defined(__AVR_ATmega2561__)
  #define MEGA
#endif

/**************************   atmega328P (Promini)  ************************************/
#if defined(PROMINI)
  #if !defined(MONGOOSE1_0)
    #define LEDPIN_PINMODE             pinMode (13, OUTPUT);
    #define LEDPIN_TOGGLE              PINB |= 1<<5;     //switch LEDPIN state (digital PIN 13)
    #define LEDPIN_OFF                 PORTB &= ~(1<<5);
    #define LEDPIN_ON                  PORTB |= (1<<5);
  #endif
  #if !defined(RCAUXPIN8) 
    #if !defined(MONGOOSE1_0)
      #define BUZZERPIN_PINMODE          pinMode (8, OUTPUT);
      #define BUZZERPIN_ON               PORTB |= 1;
      #define BUZZERPIN_OFF              PORTB &= ~1;
    #endif
  #else
    #define BUZZERPIN_PINMODE          ;
    #define BUZZERPIN_ON               ;
    #define BUZZERPIN_OFF              ;
    #define RCAUXPIN
  #endif
  #if !defined(RCAUXPIN12) && !defined(DISABLE_POWER_PIN)
    #define POWERPIN_PINMODE           pinMode (12, OUTPUT);
    #define POWERPIN_ON                PORTB |= 1<<4;
    #define POWERPIN_OFF               PORTB &= ~(1<<4); //switch OFF WMP, digital PIN 12
  #else
    #define POWERPIN_PINMODE           ;
    #define POWERPIN_ON                ;
    #define POWERPIN_OFF               ;
  #endif
  #if defined(RCAUXPIN12)
    #define RCAUXPIN
  #endif
  #define I2C_PULLUPS_ENABLE         PORTC |= 1<<4; PORTC |= 1<<5;   // PIN A4&A5 (SDA&SCL)
  #define I2C_PULLUPS_DISABLE        PORTC &= ~(1<<4); PORTC &= ~(1<<5);
  #if !defined(MONGOOSE1_0)
    #define PINMODE_LCD                pinMode(0, OUTPUT);
    #define LCDPIN_OFF                 PORTD &= ~1; //switch OFF digital PIN 0
    #define LCDPIN_ON                  PORTD |= 1;
    #define STABLEPIN_PINMODE          ;
    #define STABLEPIN_ON               ;
    #define STABLEPIN_OFF              ;
  #endif 
  #define PPM_PIN_INTERRUPT          attachInterrupt(0, rxInt, RISING); //PIN 0
  #define SPEK_SERIAL_VECT           USART_RX_vect
  #define SPEK_DATA_REG              UDR0
  //RX PIN assignment inside the port //for PORTD
  #define THROTTLEPIN                2
  #define ROLLPIN                    4
  #define PITCHPIN                   5
  #define YAWPIN                     6
  #define AUX1PIN                    7
  #define AUX2PIN                    0 // optional PIN 8 or PIN 12
  #define AUX3PIN                    1 // unused 
  #define AUX4PIN                    3 // unused 
    
  #define PCINT_PIN_COUNT            5
  #define PCINT_RX_BITS              (1<<2),(1<<4),(1<<5),(1<<6),(1<<7)
  #define PCINT_RX_PORT              PORTD
  #define PCINT_RX_MASK              PCMSK2
  #define PCIR_PORT_BIT              (1<<2)
  #define RX_PC_INTERRUPT            PCINT2_vect
  #define RX_PCINT_PIN_PORT          PIND
  #define ISR_UART                   ISR(USART_UDRE_vect)
  #define V_BATPIN                   A7    // Analog PIN 7 beim Hongkong-Board https://github.com/s-p-4-r-k/multiwii-firmware/commit/45516804b29adf365879eb181e2bfceadf9e402a
  #define PSENSORPIN                 A2    // Analog PIN 2
  
  #if defined(A0_A1_PIN_HEX) || (NUMBER_MOTOR > 6)
    #define SOFT_PWM_1_PIN_HIGH        PORTC |= 1<<0;
    #define SOFT_PWM_1_PIN_LOW         PORTC &= ~(1<<0);
    #define SOFT_PWM_2_PIN_HIGH        PORTC |= 1<<1;
    #define SOFT_PWM_2_PIN_LOW         PORTC &= ~(1<<1);  
  #else
    #define SOFT_PWM_1_PIN_HIGH        PORTD |= 1<<5;
    #define SOFT_PWM_1_PIN_LOW         PORTD &= ~(1<<5);
    #define SOFT_PWM_2_PIN_HIGH        PORTD |= 1<<6;
    #define SOFT_PWM_2_PIN_LOW         PORTD &= ~(1<<6);
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
